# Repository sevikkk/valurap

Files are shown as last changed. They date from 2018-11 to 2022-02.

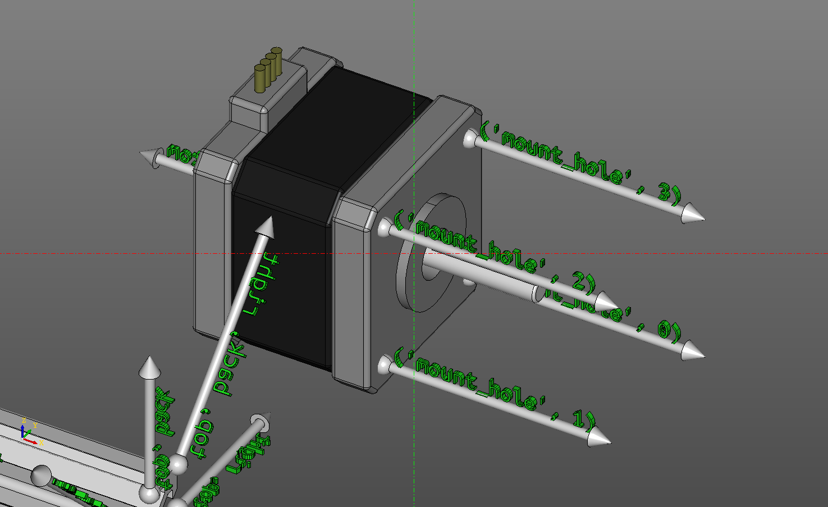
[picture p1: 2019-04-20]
zcad/examples/vitamins-3.png

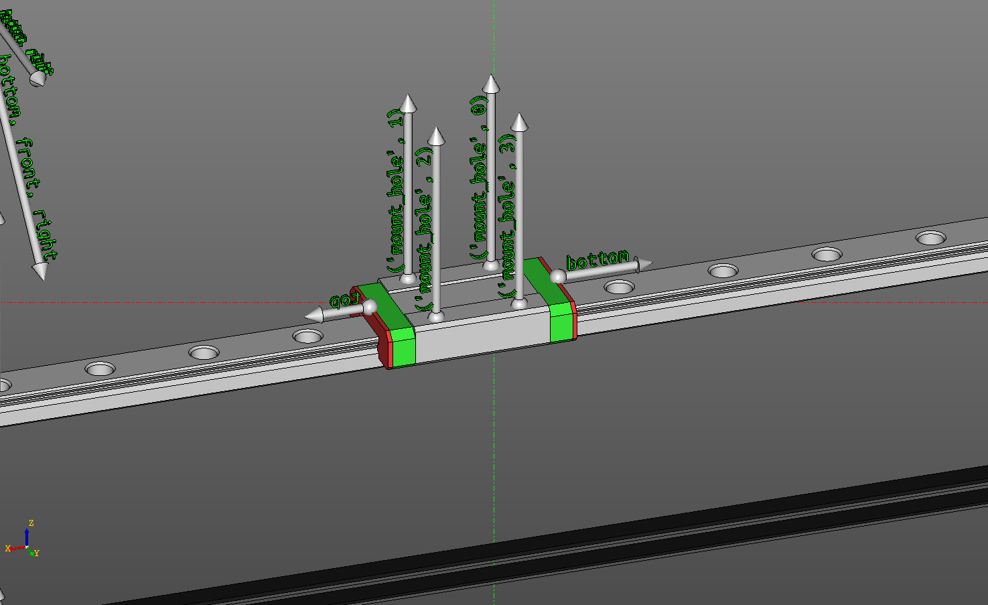
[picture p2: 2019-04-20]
zcad/examples/vitamins-4.png

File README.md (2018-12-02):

Next iteration of 3d printer
============================

Hardware
--------

* 20x20 and 20x40 v-profile, linear rails based on PVC rollers
* E3D Titan Aero Extruder

Electronics
-----------

* Orange PI Zero as main brains and network
* Mojo v3 as FPGA
* TMC2130 Stepper drivers

Directories
-----------

* fpga/ - verilog sources for SLX9 on Mojo 
* mojo_soft/ - software for mega32u4 on Mojo
* host_soft/ - python sources running on Zero
* pcbs/ - KiCad files for PCBs

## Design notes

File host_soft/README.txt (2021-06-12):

Orange PI Zero connections:

SPI1 - tms2103 SPI chain
TWI0 - SSD1306 OLED
UART1 - FPGA UART

Ext header:

     OPi        STM        OPi
PA02/UART2_RTS (RST)   |  PA10
PA03/UART2_CTS (BOOT0) |  PA18/TWI1_SCK
PA00/UART2_TX  (A10)   |  PA19/TWI1_SDA
PA01/UART2_RX  (A9)    |  PA07
GND                    |  PA06

EXT1:  EndStops
                             net
#NET "ext1_1" LOC = P58 | endstop_z1
#NET "ext1_2" LOC = P57 | endstop_z2
#NET "ext1_3" LOC = P67 | endstop_x1
#NET "ext1_4" LOC = P66 | endstop_y1
#NET "ext1_5" LOC = P75 | endstop_x2
#NET "ext1_6" LOC = P74 | endstop_y2
#NET "ext1_7" LOC = P79 | endstop_z3
#NET "ext1_8" LOC = P78 | endstop_z4

EXT2:
                         STM
NET "ext2_1" LOC = P81 | B9
NET "ext2_2" LOC = P80 | B8
NET "ext2_3" LOC = P83 | B7
NET "ext2_4" LOC = P82 | B6
NET "ext2_5" LOC = P85 | B5
NET "ext2_6" LOC = P84 | B4
NET "ext2_7" LOC = P88 | B3
NET "ext2_8" LOC = P87 | A15

EXT3:
                              net         STM
#NET "ext3_1" LOC = P93  |  stm_mosi  |  B15 (SPI2 MOSI)
#NET "ext3_2" LOC = P92  |  stm_rx    |  A3  (Serial2 RX)
#NET "ext3_3" LOC = P95  |  stm_miso  |  B14 (SPI2 MISO)
#NET "ext3_4" LOC = P94  |  stm_tx    |  A2  (Serial2 TX)
#NET "ext3_5" LOC = P98  |  stm_sck   |  B13 (SPI2 SCK)
#NET "ext3_6" LOC = P97  |  stm_int   |  A8
#NET "ext3_7" LOC = P100 |  stm_ss    |  B12 (SPI2 NSS)
#NET "ext3_8" LOC = P99  |  stm_alive |  C13 (LED1)

Disable wlan:
```
seva@orange:~$ cat /etc/modprobe.d/wlan.conf
blacklist xradio_wlan
```

Enable required devices:
```
seva@orange:~$ cat /boot/armbianEnv.txt
overlay_prefix=sun8i-h3
overlays=uart1 uart2 i2c1 i2c0 spi1 spi-spidev
param_spidev_spi_bus=1
usbstoragequirks=0x2537:0x1066:u,0x2537:0x1068:u
```

disable console on ttyS0:
```
sudo systemctl mask serial-getty@ttyS0.service
```

install cv2 into virtualenv
```
sudo apt-get install python3-opencv
cp /usr/lib/python3/dist-packages/cv2.cpython-37m-arm-linux-gnueabihf.so ~/.virtualenvs/valurap3/lib/python3.7/site-packages/
```

Enable NFS mount:
```
sudo apt-get update
sudo apt-get upgrade
sudo apt-get install nfs-common
```
add to automount entry fstab:
```
192.168.1.137:/Users/seva/src/sevasoft /home/seva/src/sevasoft nfs noauto,x-systemd.automount,soft,intr,x-systemd.idle-timeout=30 0 0
```

Virtualenv:

```
sudo apt-get install virtualenvwrapper python3-dev libffi-dev
mkvirtualenv --python=/usr/bin/python3.7 valurap3
pip install 'spidev==3.2' 'pyserial==3.4' 'pyserial-asyncio==0.4' ipython jupyter 'smbus2==0.2.3' 'luma.oled==3.1.0' OrangePi.GPIO
```

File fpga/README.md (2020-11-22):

Abbrevs
=======

* ASG - Acceleration step generator
* APG - Acceleration profile generator
* SP - SPeed integrator
* MSG - Motor step generator
* BE - buffer commands executor
* SE - S3G commands executor
* ES - EndStop debouncer

Outputs
=======

|Number | Name | Bits | Description
|--- | ---- | ---- | ---
|0  | ASG_DT_VAL | 31..0 | Length of each step in current cycle in clocks
|1  |  ASG_STEPS_VAL | 31..0 | Number of steps in current acceleration cycle
|2  | SP_CONFIG | | |
| 3 | MSG_ALL_PRE_N | 31..0 | Length of pre-pulse (after potential direction switch)
| 4 | MSG_ALL_PULSE_N | 31..0 | Length of pulse
| 5 | MSG_ALL_POST_N | 31..0 | Length of post-pulse
| 6  | MSG_X_VAL| 31..0 | Value to set X to
| 7 | MSG_CONFIG0 | 2..0 | ES mux select
|  | | 3 | Enable abort on ES change
|  | | 6..4 | SP mux select
|  | | 7 | Enable steps
|  | | 8 | Invert Direction
|  | | 9 | Set X value by stb[6]
|  | | 14..10 | Unused
|  | | 15 | Set enable output
| 8 | MSG_CONFIG1 | |
| 9 | MSG_CONFIG2 | |
| 10 | MSG_CONFIG3 | |
| 11 | MSG_CONFIG4 | |
| 12 | MSG_CONFIG5 | |
| 13 | ES_TIMEOUT | |
|14..62| Unused
|63 | SE_REG_LB | 31..0| Looped back to Input 63
 
Inputs
======

| Number | Name | Bits | Description
| --- | ---- | ---- | ---
|  0 | BE_STATUS
|  1 | APG_STATUS
|  2 | ES_STATUS
|  3 | FIFO_FREE_SPACE
|  4 | FIFO_DATA_COUNT
|  5 | MOTOR1_HOLD_X
|  6 | MOTOR2_HOLD_X
|  7 | MOTOR3_HOLD_X
|  8 | MOTOR4_HOLD_X
|  9 | MOTOR5_HOLD_X
|  10 | MOTOR6_HOLD_X
|  11 | MOTOR7_HOLD_X
|  12 | MOTOR8_HOLD_X
|  13 | MOTOR9_HOLD_X
|  14 | MOTOR10_HOLD_X
|  15 | MOTOR11_HOLD_X
|  16 | MOTOR12_HOLD_X
|  17 | MOTOR1_HOLD_X
|  18 | MOTOR2_HOLD_X
|  19 | MOTOR3_HOLD_X
|  20 | MOTOR4_HOLD_X
|  21 | MOTOR5_HOLD_X
|  22 | MOTOR6_HOLD_X
|  23 | MOTOR7_HOLD_X
|  24 | MOTOR8_HOLD_X
|  25 | MOTOR9_HOLD_X
|  26 | MOTOR10_HOLD_X
|  27 | MOTOR11_HOLD_X
|  28 | MOTOR12_HOLD_X
|  29..61 | Unused
| 62 | PENDING_INTS | 31..0 | Pending interrupts
| 63 | SE_REG_LB | 31..0 | Loopback from output 63

Interrupts
==========

|Number | Name | Description
|--- | ---- | ---
| 0 | BE_DONE | Buf Executor done (due to BUF_DONE)
| 1 | ASG_LOAD | Current accel cycle is almost done, load of next cycle params required
| 2 | ASG_DONE | Last cycle is done
| 3 | ASG_ABORT | ASG requested abort due to buffer underflow/etc
| 2..7| Unused
| 8..15 | APG_ABORTS_DONE | Aborts for corresponding channel are done
| 16..30| Unused
| 31 | SE_INT_LB | Looped back to Strobe 31

Strobes
=======

|Number | Name | Description
|--- | ---- | ---
| 0| BE start
| 1| BE abort
| 2| ASG start
| 3| ASG abort
| 4| ASG load done
| 5| SP zero | set x=0 for all SPs
| 6| MSG set X | set x=MSG_X_VAL for selected by MSG_CONFIG channels
| 7| ES unlock
| 8..15| Abort APG channel 0..7
| 16..30| Unused
| 31 | SE_INT_LB | Looped back to Int 31

S3G proto
============

Request
-------

| Offset | Size | Description
|---|---|---
| 0 | 1 |  0xD5 - header
| 1 | 1 |  Payload length (N)
| 2 | 2 |  Tag - will be copied to reply
| 4 | 1 |  Command Code
| 5 | N - 3 |  Arguments
|  N + 1| 1 | CRC

Reply
-----

| Offset | Size | Description
|---|---|---
| 0 | 1 |  0xD5 - header
| 1 | 1 |  Payload length (N)
| 2 | 2 |  Tag - copied from request or 0xFFFF
| 4 | 1 |  Reply Code
| 5 | N - 3 |  Arguments
|  N + 1| 1 | CRC

Reply Codes
-----------
|Code | Name | Description
|-----|---|---
|  80 | Interrupt | Interrupt report (originated by device)
| 0x80  | Error | Error
| 0x81  | OK | Success, can be followed by reply args
| 0x82  | BufError | Error writing to buf_exec memory because of new command arrival
| 0x85  | Unknown | Unknown command

Command Codes
-------------

|Command | CMD | Name | Args | Reply
|---|-----|---|---|---
|  0 | VERSION  | Version | -- |  OK 0xBA 0xCE
|  27 | EXT_VER  | Extended Version | -- | OK 0x01 0x00 0x01 0x00 0xCE 0x00 0x00 0x00
|  60 | OUTPUT  | Write output | 0: reg num 1..4: value | OK
|  61 | INPUT  | Read input | 0: input num | OK 0..3: Value
|  62 | STB | Send Strobes | 0..3: Mask | OK
|  63 | CLEAR  | Clear pending interrupts| 0..3: Mask
|  64 | MASK  | Mask interrupts| 0..3: Mask
|  65 | Unused (was WRITE_BUFFER in old version)
|  66 | WRITE_FIFO | Put data into buf_exec Fifo | 0: Word count 1..1+N*5: Data| {OK, BufError} 0..3: Fifo free space

Buf Executor Commands
=====================

|Format | Name | Description
|---|---|---
|0 0 X:6 X:32 | Unused
|0 1 reg_num:6 value:32 | OUTPUT | Write value to output
|1 0 0:6 X:32 | NOP | Nop
|1 0 1:6 mask:32 | STB | Send STBs
|1 0 2:6 mask:32 | WAIT_ALL | Wait for all Ints
|1 0 3:6 mask:32 | WAIT_ANY | Wait for any of Ints
|1 0 4:6 mask:32 | CLEAR | Clear INTs
|1 0 5:6 int_ext:1 value:31 | WAIT_FIFO | Wait while local or external fifo has enough data inside
|1 0 6:6 X:24 addr:8 | PARAM_ADDR | Set address pointer for APG param store
|1 0 7:6 value:32 | PARAM_WRITE_HI | Write to high 32 bits of current address
|1 0 8:6 value:32 | PARAM_WRITE_LO | Write to low 32 bits of current address, and keep it as is
|1 0 9-14:6 value:32 | PARAM_WRITE_LO_{N} | Increment current address for {N} and write to low 32 bits
|1 0 15:6 value:32 | PARAM_WRITE_LO_NC | Increment current address to 0 of next channel(32 values block) and write to low 32 bits
|1 0 5-62:6 X:32 | Unused
|1 0 63:6 X:32 | DONE | Halt and report
|1 1 X:6 X:32 | Unused

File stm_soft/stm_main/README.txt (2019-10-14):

Skeleton is generated by STM32CubeMX v5.3.0.

toolchain is from STM32 Cores by STMicroelectronics v1.7.0 installed into Arduino IDE v1.8.10.

Drivers and Middlewares folders are omitted from git repo.

env.sh file sets environment variables needed for build.

Looks like for Makefile based project "Regenerate code" parses preexisting Makefile in the wrong way.
So before regenerating delete current makefile, press "generate code" and add back lines with custom
sources at the end of file.

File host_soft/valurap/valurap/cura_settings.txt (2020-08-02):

=========== Custom FFF printer ===========
   general
     id Custom FFF printer
     name Custom FFF printer
     version 4
   metadata
     group_id 9e8ac431-269c-41fb-836f-cbf8574d42b9
     setting_version 11
     type machine
   containers:
     0 Custom FFF printer_user ('user', 'Custom FFF printer_user.inst.cfg')
        adhesion_type: 'skirt'
        draft_shield_enabled: 'True'
        ooze_shield_enabled: 'True'
        prime_tower_brim_enable: 'False'
        prime_tower_enable: 'True'
        prime_tower_position_x: '120'
        prime_tower_position_y: '100'
        retraction_combing: 'all'
        support_enable: 'True'
     6 Custom FFF printer_settings ('definition_changes', 'Custom FFF printer_settings.inst.cfg')
        machine_center_is_zero: 'True'
        machine_depth: '300'
        machine_extruder_count: '1'
        machine_heated_bed: 'True'
        machine_height: '400'
        machine_start_gcode:
          | G28 ;Home
          | G92 E0
          | G1 F200 E3
          | G92 E0
        machine_width: '320'
  extruders:
    0: --------- Extruder 1 ('extruders', 'custom_extruder_1 #2.extruder.cfg') ------- 
        general
          id: custom_extruder_1 #2
          name: Extruder 1
          version: 4
        metadata
          enabled: True
          machine: Custom FFF printer
          position: 0
          setting_version: 11
          type: extruder_train
        containers:
          0 custom_extruder_1 #2_user ('user', 'custom_extruder_1 #2_user.inst.cfg')
             clean_between_layers: 'True'
             infill_pattern: 'zigzag'
             infill_randomize_start_location: 'True'
             infill_sparse_density: '7'
             infill_wall_line_count: '1'
             prime_tower_min_volume: '1'
             prime_tower_wipe_enabled: 'False'
             retract_at_layer_change: 'True'
             retraction_amount: '1'
             retraction_speed: '10'
             speed_print: '100'
             speed_travel: '150'
             support_use_towers: 'False'
             switch_extruder_retraction_amount: '5'
             travel_avoid_supports: 'True'
             wipe_brush_pos_x: '-170'
             wipe_move_distance: '15'
             wipe_repeat_count: '3'
             wipe_retraction_enable: 'False'
             z_seam_type: 'random'
          6 custom_extruder_1 #2_settings ('definition_changes', 'custom_extruder_1 #2_settings.inst.cfg')
             material_diameter: '1.75'
=========== Custom FFF printer #2 ===========
   general
     id Custom FFF printer #2
     name Custom FFF printer #2
     version 4
   metadata
     group_id 3304d7be-4387-4436-b254-41188bad6fcd
     setting_version 11
     type machine
   containers:
     0 Custom FFF printer #2_user ('user', 'Custom FFF printer #2_user.inst.cfg')
        -- empty --
     6 Custom FFF printer #2_settings ('definition_changes', 'Custom FFF printer #2_settings.inst.cfg')
        -- empty --
  extruders:
    0: --------- Extruder 1 ('extruders', 'custom_extruder_1 #3.extruder.cfg') ------- 
        general
          id: custom_extruder_1 #3
          name: Extruder 1
          version: 4
        metadata
          enabled: True
          machine: Custom FFF printer #2
          position: 0
          setting_version: 11
          type: extruder_train
        containers:
          0 custom_extruder_1 #3_user ('user', 'custom_extruder_1 #3_user.inst.cfg')
             -- empty --
          6 custom_extruder_1 #3_settings ('definition_changes', 'custom_extruder_1 #3_settings.inst.cfg')
             -- empty --

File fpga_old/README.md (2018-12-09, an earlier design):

Abbrevs
=======

* ASG - Acceleration step generator
* APG - Acceleration profile generator
* MSG - Motor step generator
* BE - buffer commands executor
* SE - S3G commands executor

Outputs
=======

|Number | Name | Bits | Description
|--- | ---- | ---- | ---
|0  |  LEDS | 7..0 | On-board LEDs
|  | | 31..8 | Unused
|1  |  ASG_STEPS_VAL | 31..0 | Number of steps in current acceleration cycle
|2  | ASG_DT_VAL | 31..0 | Length of each step in current cycle in clocks
|3  | ASG_CONTROL | 0 | Set steps limit
| | | 1 | Set DT limit
| | | 2 | Reset steps
| | | 3 | Reset DT
| | | 4..7 | Unused
| | | 8 | APG_X set X
| | | 9 | APG_X set V
| | | 10 | APG_X set A
| | | 11 | APG_X set J
| | | 12 | APG_X set JJ
| | | 13 | APG_X set target V
| 4 | MSG_ALL_PRE_N | 31..0 | Length of pre-pulse (after potential direction switch)
| 5 | MSG_ALL_PULSE_N | 31..0 | Length of pulse
| 6 | MSG_ALL_POST_N | 31..0 | Length of post-pulse
| 7 | MSG_CONTROL | 0 | X-motor enable (inverted output, 0 - disabled, 1 - enabled)
| | | 31..1 | Unused
| 8 | APG_X_X_VAL_LO | 31..0 | X channel X value (lower half)
| 9 | APG_X_X_VAL_HI | 31..0 | X channel X value (higher half)
| 10 | APG_X_V_VAL | 31..0 | X channel V value
| 11 | APG_X_A_VAL | 31..0 | X channel A value
| 12 | APG_X_J_VAL | 31..0 | X channel J value
| 13 | APG_X_JJ_VAL | 31..0 | X channel JJ value
| 14 | APG_X_TARGET_V_VAL | 31..0 | X channel target velocity value
| 15 | APG_X_ABORT_A_VAL | 31..0 | X channel abort acceleration value
|16..61| Unused
|62 | BE_START_ADDR | 15..0 | Start address for buf_exec
|63 | SE_REG_LB | 31..0| Looped back to Input 63
 
Inputs
======

| Number | Name | Bits | Description
| --- | ---- | ---- | ---
|  0 | ASG_DT | 31..0 | Current accel step clock number
|  1 | ASG_STEP | 31..0 | Current step in accel cycle
|  2..61 | Unused
|  62 | BE_CONTROL | 31 | BE_BUSY - buf_exec is executing
| | | 30 | BE_WAITING - buf_exec is waiting for interrupt
| | |29..24| Unused
| | | 23..16 | BE_ERROR - current error code
| | | 15..0 | BE_PC - current PC of buf_exec
| 63 | SE_REG_LB | 31..0 | Loopback from output 63

Interrupts
==========

|Number | Name | Description
|--- | ---- | ---
| 0 | ASG_DONE | Current accel cycle is done, load required
| 1 | ASG_ABORT | Aborting current activity as new params were not loaded in time
| 2..29| Unused
| 30 | BE_COMPLETE | buf_exec done executing
| 31 | SE_INT_LB | Looped back to Strobe 0

Strobes
=======

|Number | Name | Description
|--- | ---- | ---
| 0 | ASG_LOAD | Load parameters of current accel cycle
| 1..28| Unused
| 29 | BE_START | Start execution for buf_exec
| 30 | BE_ABORT | Abort buf_exec execution
| 31 | SE_INT_LB | Looped back to Int 31

S3G proto
============

Request
-------

| Offset | Size | Description
|---|---|---
| 0 | 1 |  0xD5 - header
| 1 | 1 |  Payload length (N)
| 2 | 2 |  Tag - will be copied to reply
| 4 | 1 |  Command Code
| 5 | N - 3 |  Arguments
|  N + 1| 1 | CRC

Reply
-----

| Offset | Size | Description
|---|---|---
| 0 | 1 |  0xD5 - header
| 1 | 1 |  Payload length (N)
| 2 | 2 |  Tag - copied from request or 0xFFFF
| 4 | 1 |  Reply Code
| 5 | N - 3 |  Arguments
|  N + 1| 1 | CRC

Reply Codes
-----------
|Code | Name | Description
|-----|---|---
|  80 | Interrupt | Interrupt report (originated by device)
| 0x80  | Error | Error
| 0x81  | OK | Success, can be followed by reply args
| 0x82  | BufError | Error writing to buf_exec memory because of new command arrival
| 0x85  | Unknown | Unknown command

Command Codes
-------------

|Command | CMD | Name | Args | Reply
|---|-----|---|---|---
|  0 | VERSION  | Version | -- |  OK 0xBA 0xCE
|  27 | EXT_VER  | Extended Version | -- | OK 0x01 0x00 0x01 0x00 0xCE 0x00 0x00 0x00
|  60 | OUTPUT  | Write output | 0: reg num 1..4: value | OK
|  61 | INPUT  | Read input | 0: input num | OK 0..3: Value
|  62 | STB | Send Strobes | 0..3: Mask | OK
|  63 | CLEAR  | Clear pending interrupts| 0..3: Mask
|  64 | MASK  | Mask interrupts| 0..3: Mask
|  65 | WRITE_BUFFER | Write buf_exec memory| 0: Word count 1..2: Offset 3..3+N*5: Data| {OK, BufError} 0..1: Addr 2: Curent Error 3..4: PC

Buf Executor Commands
=====================

|Format | Name | Description
|---|---|---
|0 0 X:6 X:32 | Unused
|0 1 reg_num:6 value:32 | OUTPUT | Write value to output
|1 0 0:6 X:32 | NOP | Nop
|1 0 1:6 mask:32 | STB | Send STBs
|1 0 2:6 mask:32 | WAIT_ALL | Wait for all Ints
|1 0 3:6 mask:32 | WAIT_ANY | Wait for any of Ints
|1 0 4:6 masK:32 | CLEAR | Clear INTs
|1 0 5-62:6 X:32 | Unused
|1 0 63:6 X:32 | DONE | Halt and report
|1 1 X:6 X:32 | Unused

Utilization for single full channel
===================================

```
Device Utilization Summary:

Slice Logic Utilization:
  Number of Slice Registers:                 1,395 out of  11,440   12%
    Number used as Flip Flops:               1,395
    Number used as Latches:                      0
    Number used as Latch-thrus:                  0
    Number used as AND/OR logics:                0
  Number of Slice LUTs:                      2,315 out of   5,720   40%
    Number used as logic:                    2,303 out of   5,720   40%
      Number using O6 output only:           1,690
      Number using O5 output only:             122
      Number using O5 and O6:                  491
      Number used as ROM:                        0
    Number used as Memory:                       2 out of   1,440    1%
      Number used as Dual Port RAM:              0
      Number used as Single Port RAM:            0
      Number used as Shift Register:             2
        Number using O6 output only:             2
        Number using O5 output only:             0
        Number using O5 and O6:                  0
    Number used exclusively as route-thrus:     10
      Number with same-slice register load:      5
      Number with same-slice carry load:         5
      Number with other load:                    0

Slice Logic Distribution:
  Number of occupied Slices:                   712 out of   1,430   49%
  Nummber of MUXCYs used:                      764 out of   2,860   26%
  Number of LUT Flip Flop pairs used:        2,524
    Number with an unused Flip Flop:         1,180 out of   2,524   46%
    Number with an unused LUT:                 209 out of   2,524    8%
    Number of fully used LUT-FF pairs:       1,135 out of   2,524   44%
    Number of slice register sites lost
      to control set restrictions:               0 out of  11,440    0%

  A LUT Flip Flop pair for this architecture represents one LUT paired with
  one Flip Flop within a slice.  A control set is a unique combination of
  clock, reset, set, and enable signals for a registered element.
  The Slice Logic Distribution report is not meaningful if the design is
  over-mapped for a non-slice resource or if Placement fails.

IO Utilization:
  Number of bonded IOBs:                        23 out of     102   22%
    Number of LOCed IOBs:                       20 out of      23   86%
    IOB Flip Flops:                              1

Specific Feature Utilization:
  Number of RAMB16BWERs:                        21 out of      32   65%
  Number of RAMB8BWERs:                          0 out of      64    0%
  Number of BUFIO2/BUFIO2_2CLKs:                 0 out of      32    0%
  Number of BUFIO2FB/BUFIO2FB_2CLKs:             0 out of      32    0%
  Number of BUFG/BUFGMUXs:                       1 out of      16    6%
    Number used as BUFGs:                        1
    Number used as BUFGMUX:                      0
  Number of DCM/DCM_CLKGENs:                     0 out of       4    0%
  Number of ILOGIC2/ISERDES2s:                   0 out of     200    0%
  Number of IODELAY2/IODRP2/IODRP2_MCBs:         0 out of     200    0%
  Number of OLOGIC2/OSERDES2s:                   1 out of     200    1%
    Number used as OLOGIC2s:                     1
    Number used as OSERDES2s:                    0
  Number of BSCANs:                              0 out of       4    0%
  Number of BUFHs:                               0 out of     128    0%
  Number of BUFPLLs:                             0 out of       8    0%
  Number of BUFPLL_MCBs:                         0 out of       4    0%
  Number of DSP48A1s:                            0 out of      16    0%
  Number of ICAPs:                               0 out of       1    0%
  Number of MCBs:                                0 out of       2    0%
  Number of PCILOGICSEs:                         0 out of       2    0%
  Number of PLL_ADVs:                            0 out of       2    0%
  Number of PMVs:                                0 out of       1    0%
  Number of STARTUPs:                            0 out of       1    0%
  Number of SUSPEND_SYNCs:                       0 out of       1    0%
```

Utilization for two full channels
===================================

```
Device Utilization Summary:

Slice Logic Utilization:
  Number of Slice Registers:                 1,856 out of  11,440   16%
    Number used as Flip Flops:               1,856
    Number used as Latches:                      0
    Number used as Latch-thrus:                  0
    Number used as AND/OR logics:                0
  Number of Slice LUTs:                      3,304 out of   5,720   57%
    Number used as logic:                    3,291 out of   5,720   57%
      Number using O6 output only:           2,336
      Number using O5 output only:             152
      Number using O5 and O6:                  803
      Number used as ROM:                        0
    Number used as Memory:                       2 out of   1,440    1%
      Number used as Dual Port RAM:              0
      Number used as Single Port RAM:            0
      Number used as Shift Register:             2
        Number using O6 output only:             2
        Number using O5 output only:             0
        Number using O5 and O6:                  0
    Number used exclusively as route-thrus:     11
      Number with same-slice register load:      5
      Number with same-slice carry load:         6
      Number with other load:                    0

Slice Logic Distribution:
  Number of occupied Slices:                 1,010 out of   1,430   70%
  Nummber of MUXCYs used:                    1,272 out of   2,860   44%
  Number of LUT Flip Flop pairs used:        3,508
    Number with an unused Flip Flop:         1,779 out of   3,508   50%
    Number with an unused LUT:                 204 out of   3,508    5%
    Number of fully used LUT-FF pairs:       1,525 out of   3,508   43%
    Number of slice register sites lost
      to control set restrictions:               0 out of  11,440    0%

  A LUT Flip Flop pair for this architecture represents one LUT paired with
  one Flip Flop within a slice.  A control set is a unique combination of
  clock, reset, set, and enable signals for a registered element.
  The Slice Logic Distribution report is not meaningful if the design is
  over-mapped for a non-slice resource or if Placement fails.

IO Utilization:
  Number of bonded IOBs:                        26 out of     102   25%
    Number of LOCed IOBs:                       20 out of      26   76%
    IOB Flip Flops:                              2

Specific Feature Utilization:
  Number of RAMB16BWERs:                        21 out of      32   65%
  Number of RAMB8BWERs:                          0 out of      64    0%
  Number of BUFIO2/BUFIO2_2CLKs:                 0 out of      32    0%
  Number of BUFIO2FB/BUFIO2FB_2CLKs:             0 out of      32    0%
  Number of BUFG/BUFGMUXs:                       1 out of      16    6%
    Number used as BUFGs:                        1
    Number used as BUFGMUX:                      0
  Number of DCM/DCM_CLKGENs:                     0 out of       4    0%
  Number of ILOGIC2/ISERDES2s:                   0 out of     200    0%
  Number of IODELAY2/IODRP2/IODRP2_MCBs:         0 out of     200    0%
  Number of OLOGIC2/OSERDES2s:                   2 out of     200    1%
    Number used as OLOGIC2s:                     2
    Number used as OSERDES2s:                    0
  Number of BSCANs:                              0 out of       4    0%
  Number of BUFHs:                               0 out of     128    0%
  Number of BUFPLLs:                             0 out of       8    0%
  Number of BUFPLL_MCBs:                         0 out of       4    0%
  Number of DSP48A1s:                            0 out of      16    0%
  Number of ICAPs:                               0 out of       1    0%
  Number of MCBs:                                0 out of       2    0%
  Number of PCILOGICSEs:                         0 out of       2    0%
  Number of PLL_ADVs:                            0 out of       2    0%
  Number of PMVs:                                0 out of       1    0%
  Number of STARTUPs:                            0 out of       1    0%
  Number of SUSPEND_SYNCs:                       0 out of       1    0%
```

Utilization for 2 full channels and 2 XVA only channels
=======================================================

Also X is limited to 48 bits. But it does not fit anyway.
Patch is in `patch/4chan.patch`.

```
Slice Logic Utilization:
 Number of Slice Registers:            2523  out of  11440    22%
 Number of Slice LUTs:                 7017  out of   5720   122% (*)
    Number used as Logic:              7015  out of   5720   122% (*)
    Number used as Memory:                2  out of   1440     0%
       Number used as SRL:                2

Slice Logic Distribution:
 Number of LUT Flip Flop pairs used:   7212
   Number with an unused Flip Flop:    4689  out of   7212    65%
   Number with an unused LUT:           195  out of   7212     2%
   Number of fully used LUT-FF pairs:  2328  out of   7212    32%
   Number of unique control sets:        73

IO Utilization:
 Number of IOs:                          37
 Number of bonded IOBs:                  32  out of    102    31%

Specific Feature Utilization:
 Number of Block RAM/FIFO:               21  out of     32    65%
    Number using Block RAM only:         21
 Number of BUFG/BUFGCTRLs:                1  out of     16     6%
```

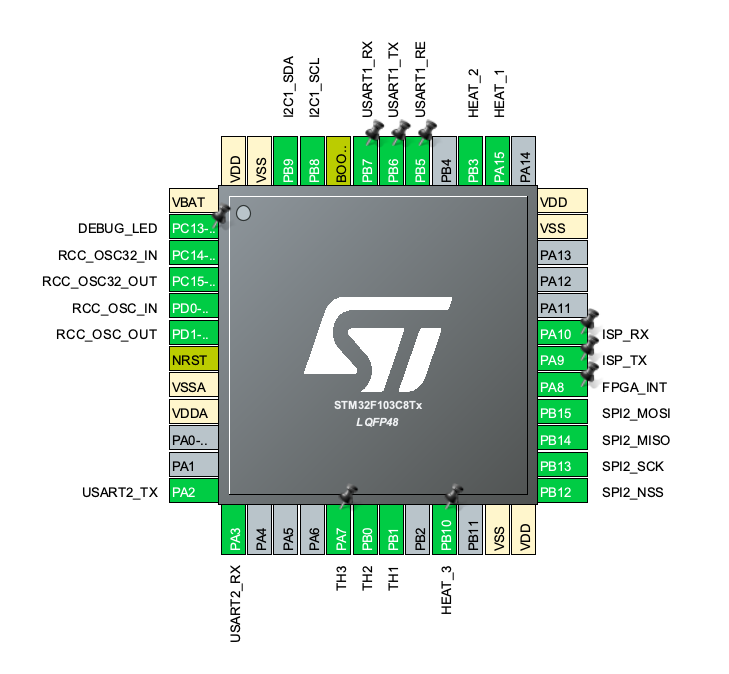
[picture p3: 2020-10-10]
stm_soft/stm_main/stm_main_pins.png

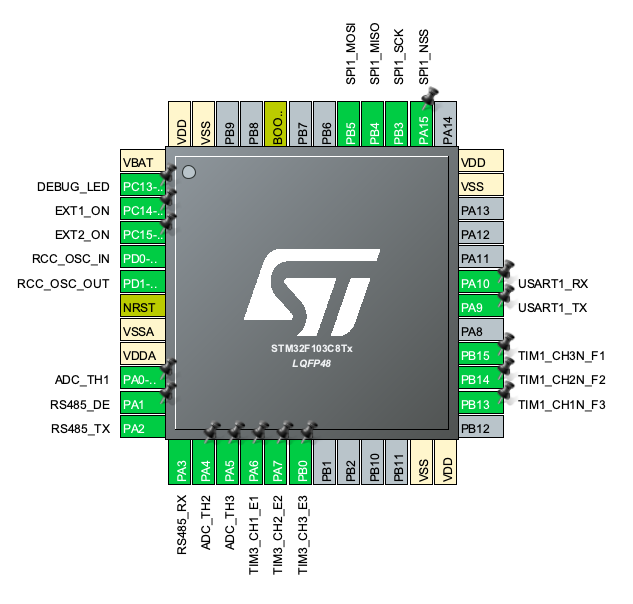
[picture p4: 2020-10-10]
stm_soft/stm_thermo/stm_thermo_pins.png

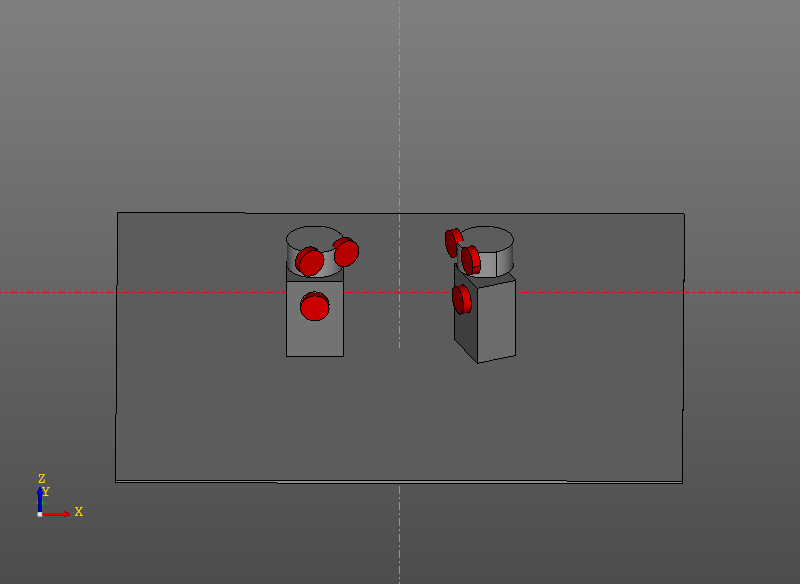
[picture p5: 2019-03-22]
zcad/examples/robot.png

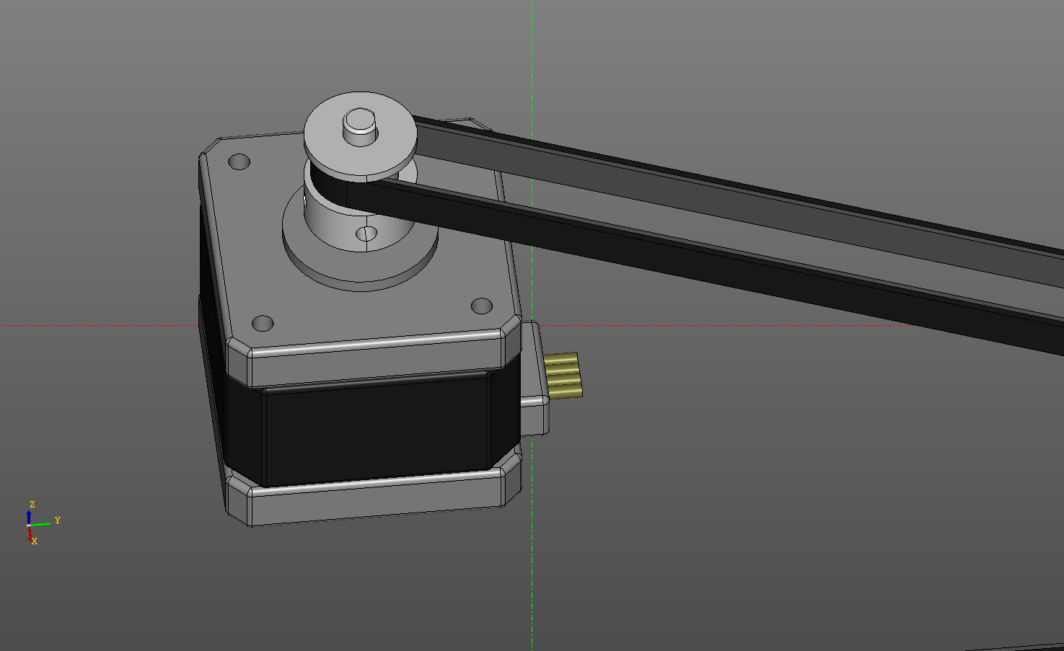
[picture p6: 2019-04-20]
zcad/examples/vitamins-2.png

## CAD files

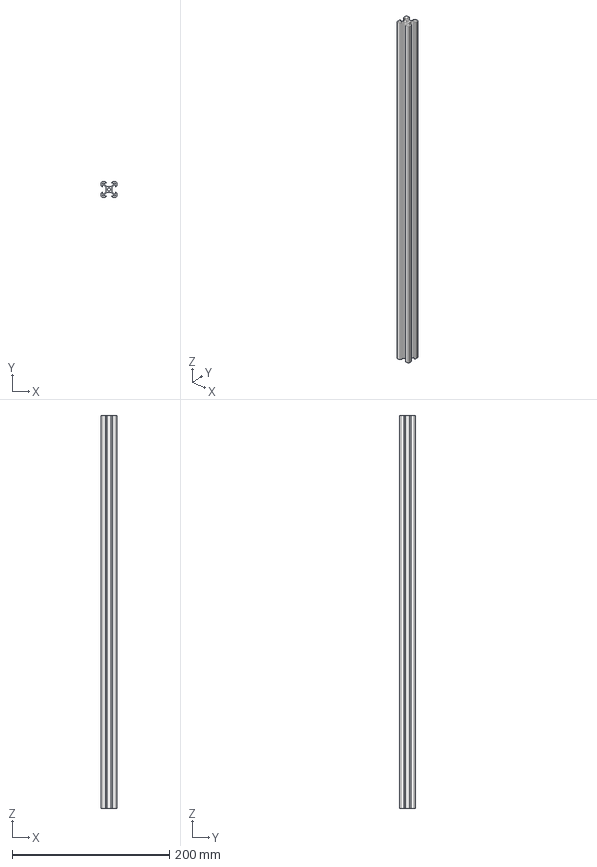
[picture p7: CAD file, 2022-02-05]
freecad/extra_fcstds/frame_assembly.FCStd
20.0 x 20.0 x 500.0 mm

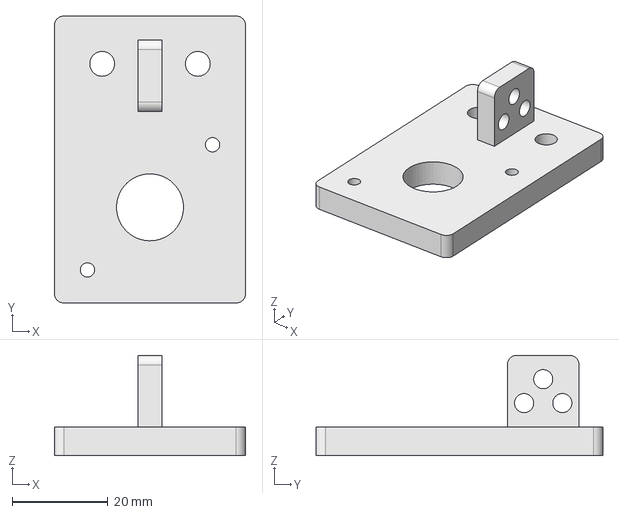
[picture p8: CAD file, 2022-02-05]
freecad/extra_fcstds/camera_mount.FCStd
40.0 x 60.0 x 21.0 mm

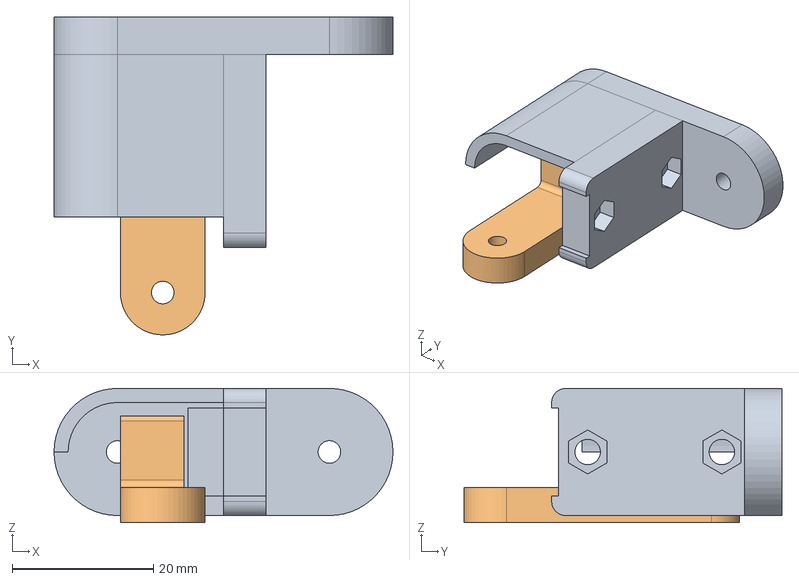
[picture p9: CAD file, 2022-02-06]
freecad/left_z_opto_mount.FCStd
48.0 x 45.0 x 19.0 mm
opto_mount
opto_probe

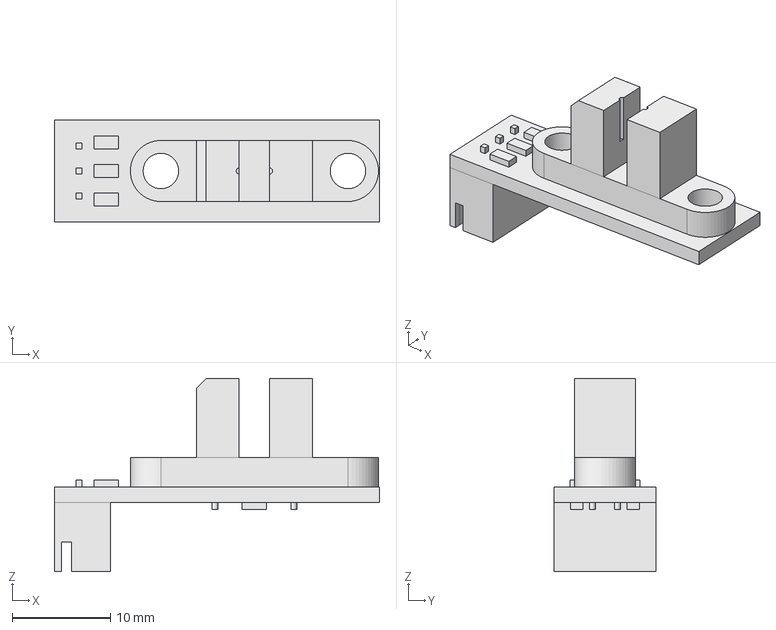
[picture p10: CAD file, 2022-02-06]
freecad/vitamins/optostop.FCStd
33.0 x 10.4 x 19.6 mm

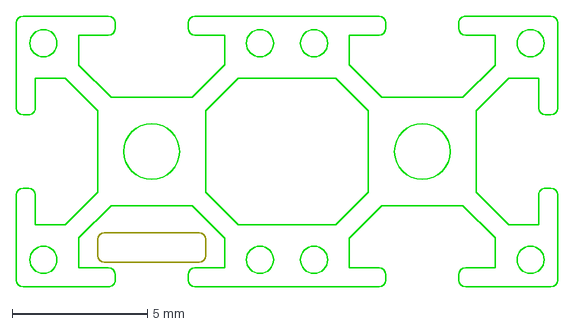
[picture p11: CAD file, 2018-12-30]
scad/vitamins/paratslot.dxf
20.0 x 10.0 mm

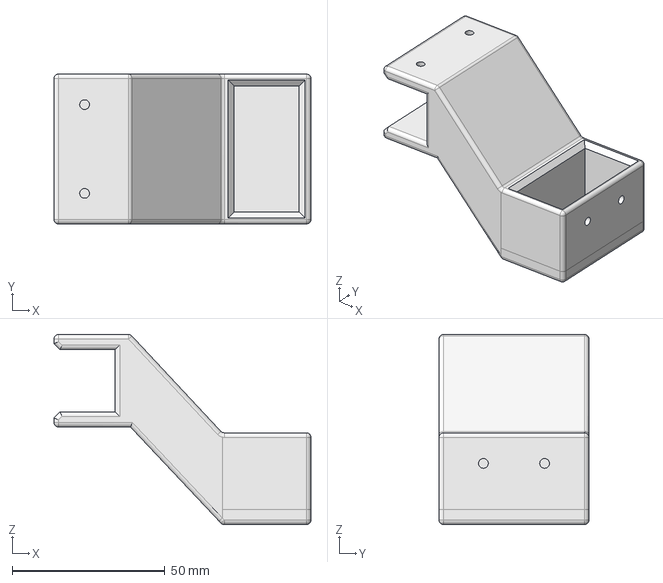
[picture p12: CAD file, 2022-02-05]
freecad/extra_fcstds/second_heater_holder.FCStd
84.0 x 49.0 x 62.2 mm

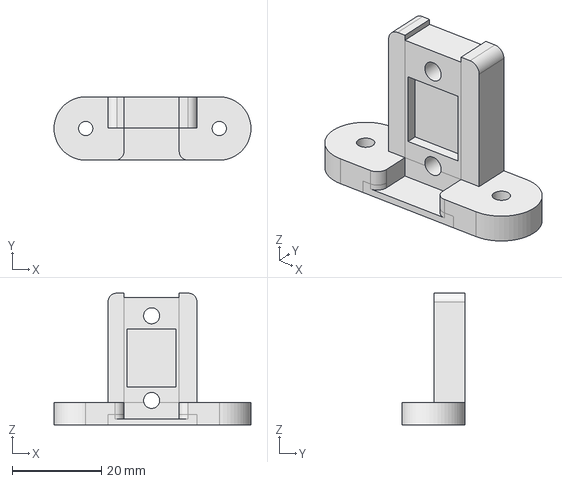
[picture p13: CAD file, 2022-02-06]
freecad/left_x_opto_mount.FCStd
44.2 x 14.2 x 29.6 mm

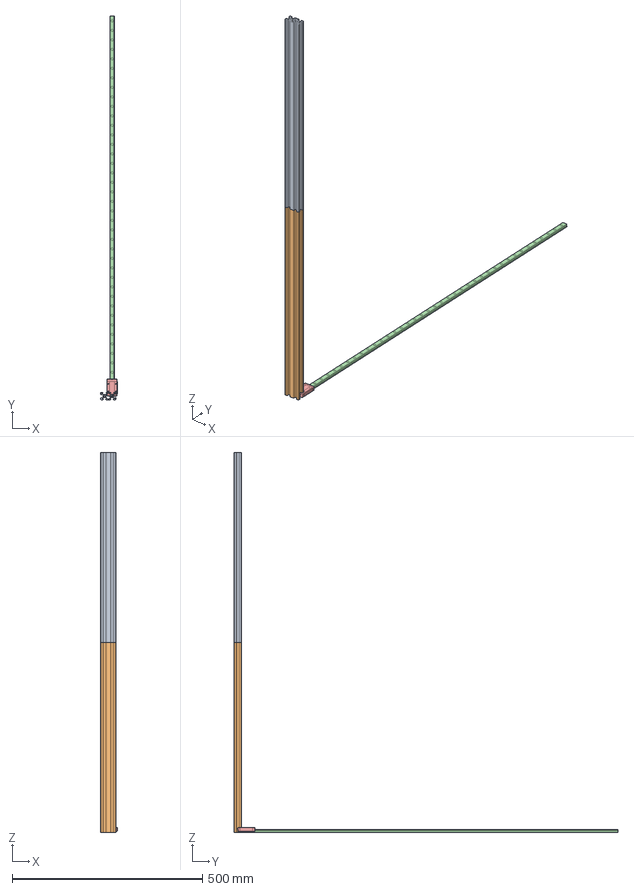
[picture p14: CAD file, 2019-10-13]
freecad/vitamins/mgr12r450.FCStd
43.5 x 1010.0 x 1000.0 mm
Clear anodized V-Slot 20x40mm Length: 1000.0
Clear anodized V-Slot 20x40mm Length: 500.0
MGNR12R450
MGNR12R1000
MGN12H
MGN12H_001
MGNR12R1000_001
MGNR12R450_001

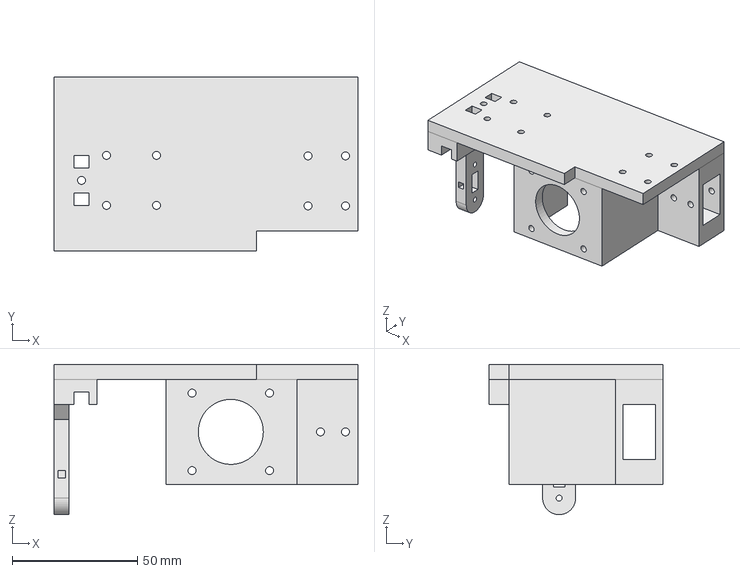
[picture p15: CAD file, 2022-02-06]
freecad/left_y_carriage_plate.FCStd
121.6 x 69.5 x 60.1 mm

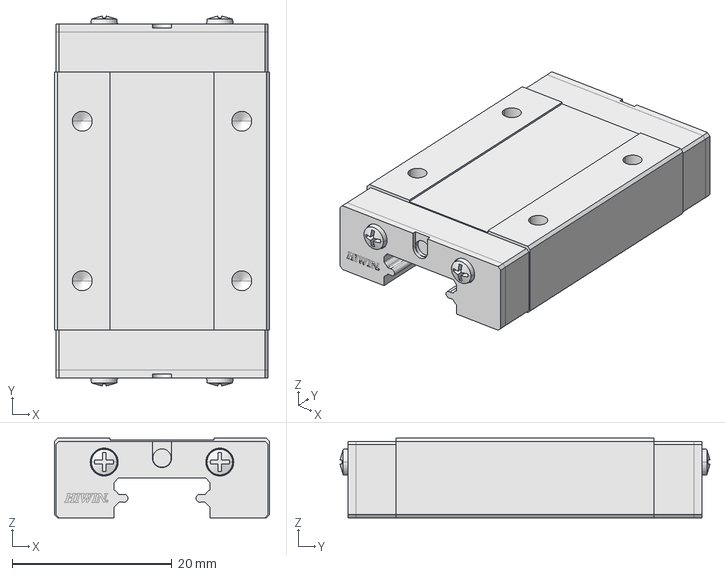
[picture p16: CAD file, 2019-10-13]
freecad/vitamins/mgn12h.FCStd
27.0 x 46.4 x 10.0 mm

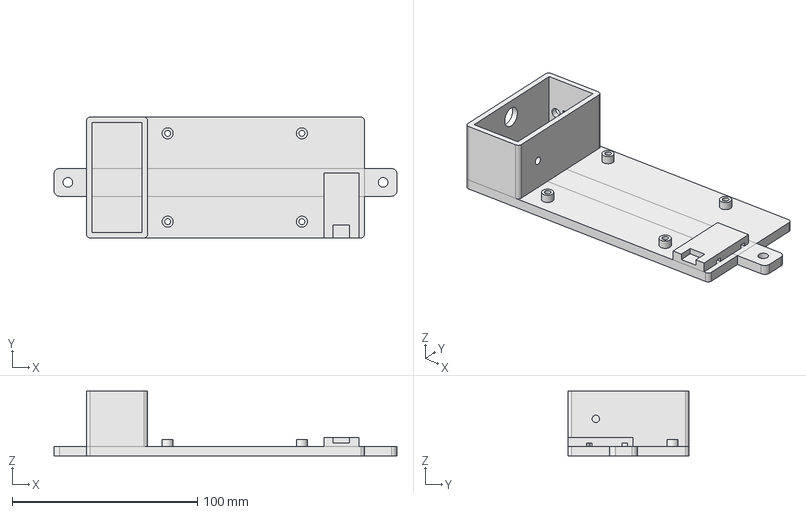
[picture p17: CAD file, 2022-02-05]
freecad/extra_fcstds/tc_box.FCStd
185.0 x 65.2 x 35.0 mm

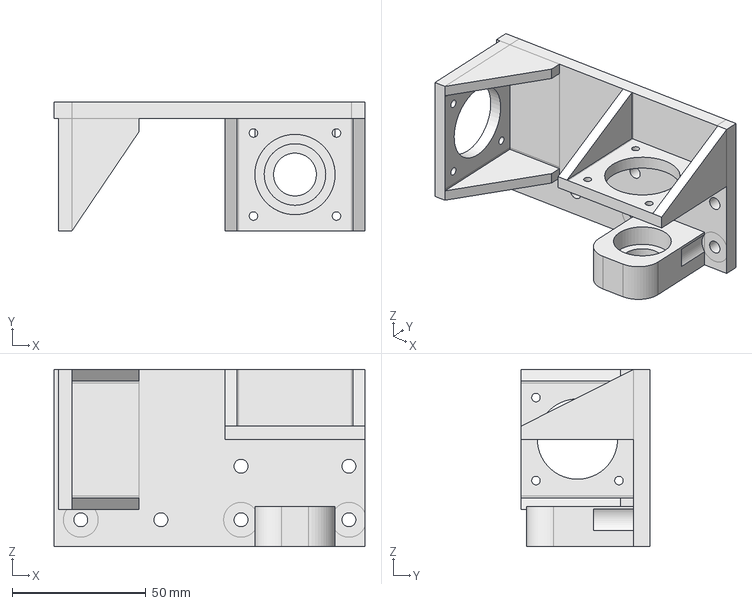
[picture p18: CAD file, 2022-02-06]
freecad/left_y_motor_plate.FCStd
116.2 x 48.0 x 66.2 mm

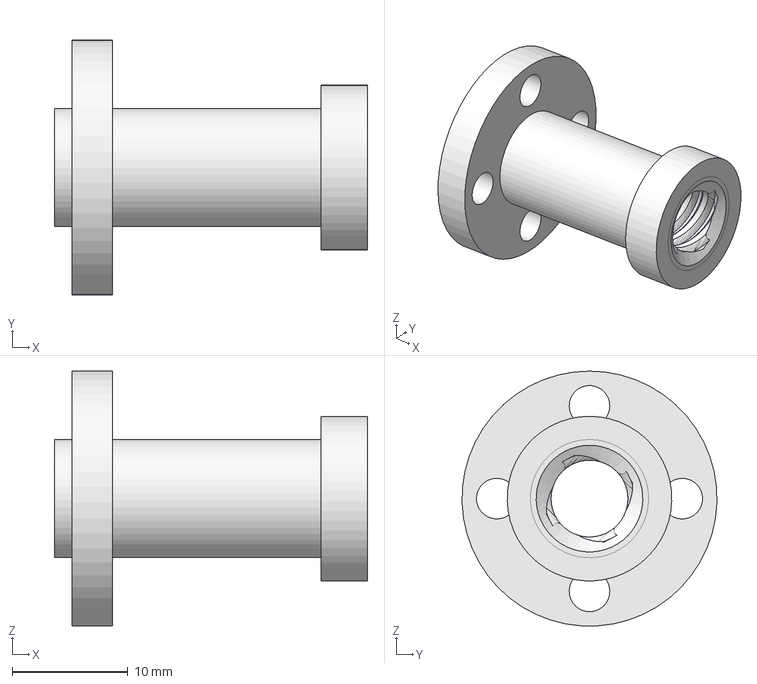
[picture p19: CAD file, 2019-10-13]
freecad/vitamins/nut8.FCStd
27.0 x 22.0 x 22.0 mm

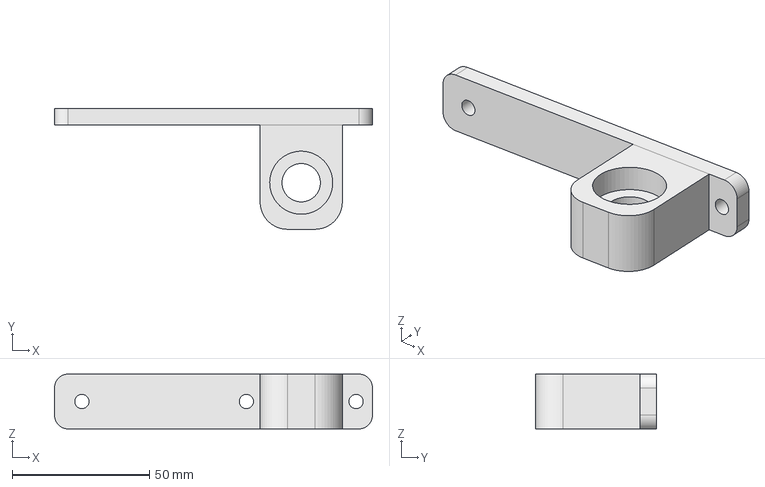
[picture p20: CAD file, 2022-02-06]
freecad/left_z_rod_support.FCStd
116.0 x 44.0 x 20.0 mm

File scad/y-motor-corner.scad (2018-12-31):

module y_motor_corner(is_left) {
    k = is_left?1:0;
    mirror([k,0,0])
    difference() {
        union() {
            difference() {
                union() {
                    translate([-25,-25,0]) cube([50,50,5]);
                    translate([22,-25,-45]) cube([3,50,50]);
                    translate([-25,-25,-45]) cube([50,3,50]);
                    translate([-25,22,-45]) cube([50,3,50]);
                    translate([-25,-25,-65]) cube([3,65,70]);
                };
                translate([-50,-30,-130]) rotate([0,0,0]) cube([100,100,100]);
                translate([0,0, -50]) rotate([0,0,0]) cylinder(d=25, h=100);
            };
            translate([-25,8,-66]) cube([3,32,89]);

        };
        translate([-30, 14,-55]) rotate([0,90,0]) cylinder(d=5, h=10);
        translate([-30,34,-55]) rotate([0,90,0]) cylinder(d=5, h=10);
        translate([-30,34,-25]) rotate([0,90,0]) cylinder(d=5, h=10);
        translate([-30,34, 17]) rotate([0,90,0]) cylinder(d=5, h=10);
        translate([-30, 14, 17]) rotate([0,90,0]) cylinder(d=5, h=10);
        translate([15.5, 15.5, -5]) rotate([0,0,0]) cylinder(d=3, h=12);
        translate([15.5, -15.5, -5]) rotate([0,0,0]) cylinder(d=3, h=12);
        translate([-15.5, 15.5, -5]) rotate([0,0,0]) cylinder(d=3, h=12);
        translate([-15.5, -15.5, -5]) rotate([0,0,0]) cylinder(d=3, h=12);

    }
}

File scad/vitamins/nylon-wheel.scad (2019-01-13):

wheel_23mm   = ["Nylon Wheel 23 mm", 7.8, 7.4, 14, 5, 7, 5, 17.5];
wheel_34mm   = ["Nylon Wheel 34.5 mm", 12.25, 12, 19, 6, 11, 6, 25];

function wheel_type(type) = type[0];
function wheel_circle_offset(type) = type[1];
function wheel_circle_diameter(type) = type[2];
function wheel_bearing_od(type) = type[3];
function wheel_bearing_height(type) = type[4];
function wheel_width(type) = type[5];
function wheel_bearing_id(type) = type[6];
function wheel_v_slot_offset(type) = type[7];

module nylon_wheel(type)
{
    color("LightGrey",.9)
    difference()
    {
        union()
        {
            rotate_extrude(convexity = 10, $fn = 64)
            translate([wheel_circle_offset(type), 0, 0])
            circle(d = wheel_circle_diameter(type), $fn = 64);
            cylinder(d=wheel_bearing_od(type), h=wheel_bearing_height(type), center=true);
        }
        translate([0,0,wheel_width(type)/2])
        cylinder(d=50,h=10);
        translate([0,0,-10 - wheel_width(type)/2])
        cylinder(d=50,h=10);
        cylinder(d=wheel_bearing_id(type),h=10,center=true,$fn=24);
    }
}

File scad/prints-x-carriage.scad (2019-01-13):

include <x-carriage-plate.scad>

translate([0,0,21.5]) rotate([180,0,0]) x_carriage_plate(14, 17.5, 2.5);
//translate([0,80,21.5]) rotate([180,0,0]) x_carriage_plate(14, 17.5, 2.5);

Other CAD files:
freecad/vitamins/tcst2103.FCStd
freecad/steppers_board_mount.FCStd
freecad/vitamins/gp1s51.FCStd
freecad/titan_mount_plate.FCStd
scad/prints-x-end.scad
freecad/left_y_idler_plate.FCStd
freecad/vitamins/coupler.FCStd
freecad/x_carriage_plate.FCStd
scad/prints-y-corners.scad
scad/top.scad
scad/vitamins/ball-bearings.scad
scad/vitamins/bars.scad
scad/vitamins/belts.scad
scad/vitamins/bulldog.scad
scad/vitamins/cable_strip.scad
scad/vitamins/colors.scad
scad/vitamins/components.scad
scad/vitamins/d-connectors.scad
scad/vitamins/e3d_hot_end.scad
scad/vitamins/electronics.scad
scad/vitamins/extruders.scad
scad/vitamins/fans.scad
scad/vitamins/hot_ends.scad
scad/vitamins/jhead_hot_end.scad
scad/vitamins/light_strips.scad
scad/vitamins/linear-bearings.scad
scad/vitamins/m90_hot_end.scad
scad/vitamins/microswitch.scad
scad/vitamins/nuts.scad
scad/vitamins/o_rings.scad
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

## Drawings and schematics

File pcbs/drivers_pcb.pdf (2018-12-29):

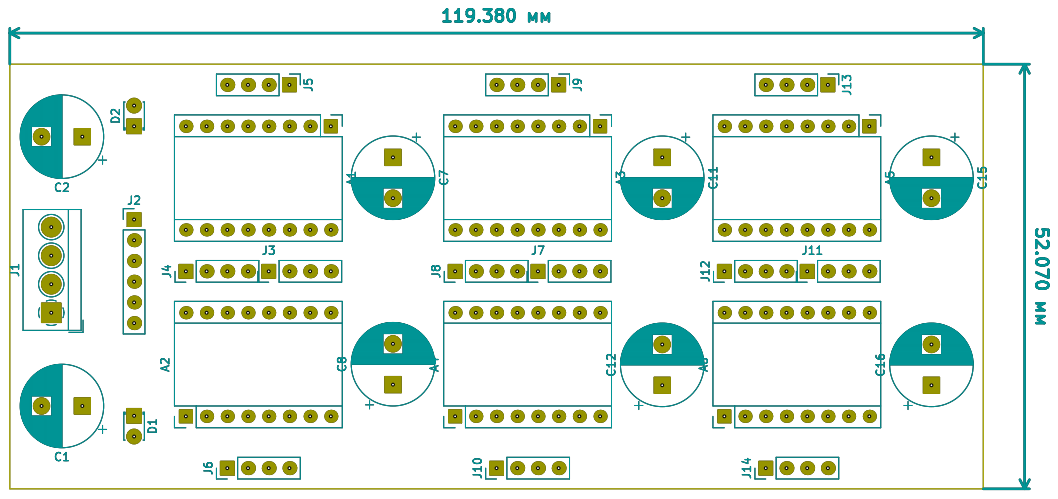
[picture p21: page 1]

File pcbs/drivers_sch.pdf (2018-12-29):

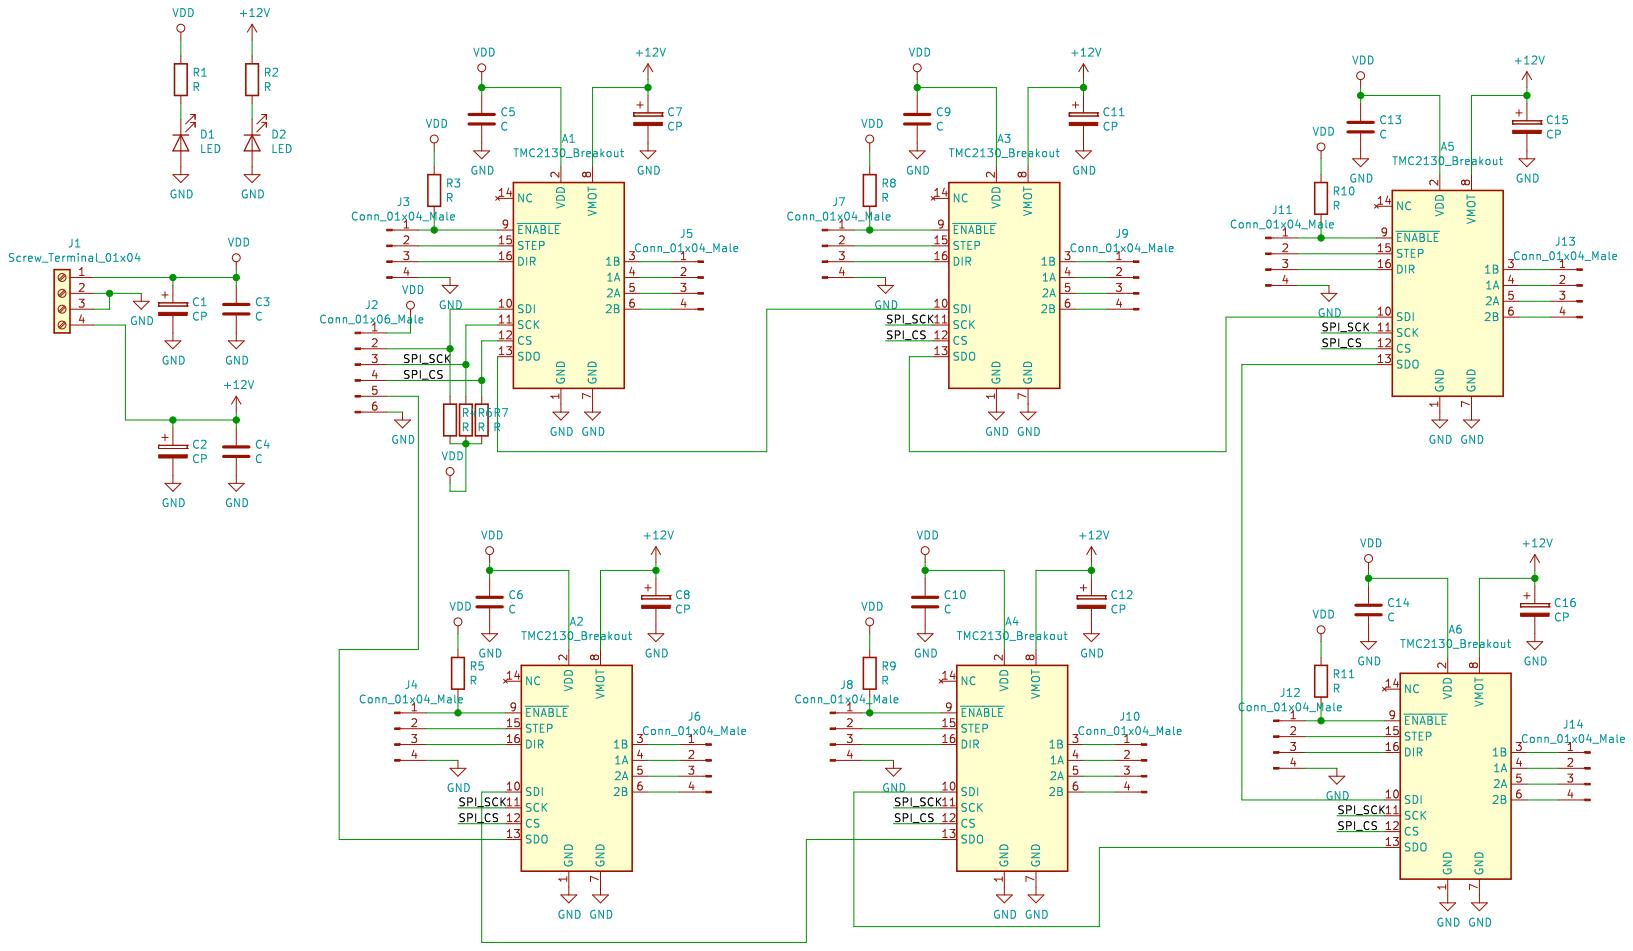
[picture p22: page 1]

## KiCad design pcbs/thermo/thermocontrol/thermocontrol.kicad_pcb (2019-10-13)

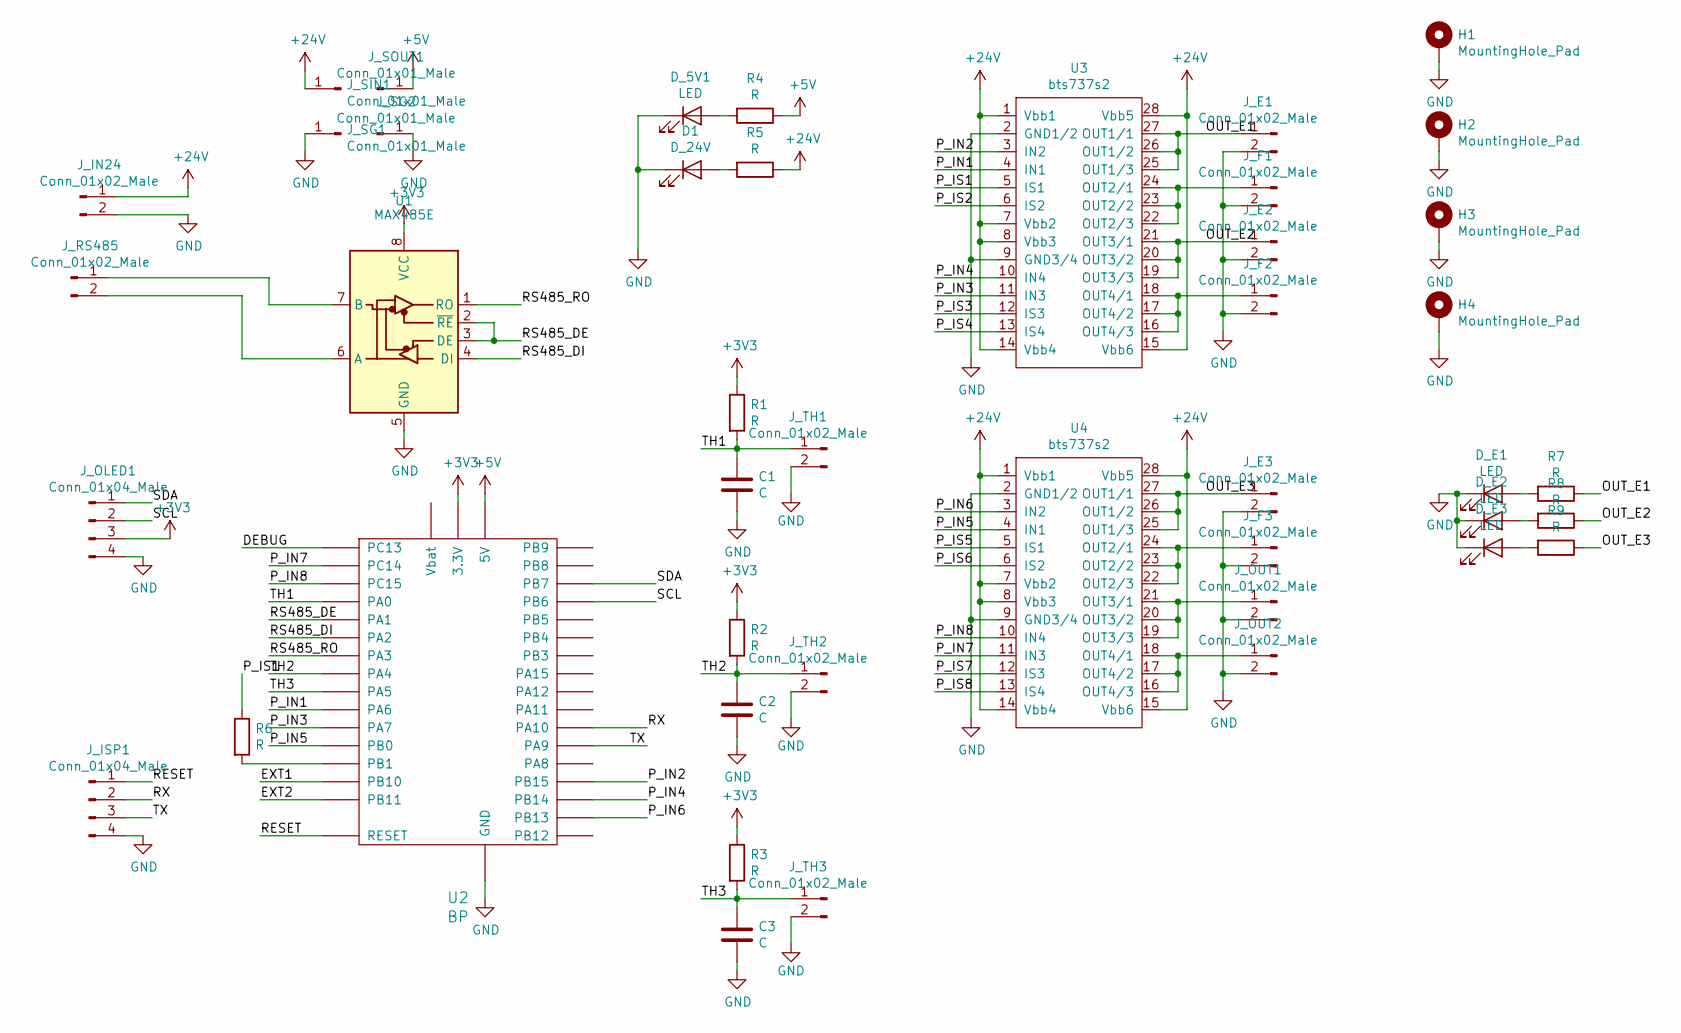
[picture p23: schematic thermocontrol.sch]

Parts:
C1, C2, C3: C; C_0805_2012Metric
D1: D_24V; LED_0805_2012Metric
D_5V1: LED; LED_0805_2012Metric
D_E1, D_E2, D_E3: LED; LED_0805_2012Metric
H1, H2, H3, H4: MountingHole_Pad; MountingHole_3.2mm_M3_DIN965_Pad
J_E1, J_E2, J_E3: Conn_01x02_Male; TerminalBlock_MetzConnect_Type011_RT05502HBWC_1x02_P5.00mm_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
J_F1, J_F2, J_F3: Conn_01x02_Male; PinHeader_1x02_P2.54mm_Vertical
J_IN24: Conn_01x02_Male; TerminalBlock_MetzConnect_Type011_RT05502HBWC_1x02_P5.00mm_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
J_ISP1: Conn_01x04_Male; PinHeader_2x02_P2.54mm_Vertical
J_OLED1: Conn_01x04_Male; PinHeader_2x02_P2.54mm_Vertical
J_OUT1, J_OUT2: Conn_01x02_Male; PinHeader_1x02_P2.54mm_Vertical
J_RS485: Conn_01x02_Male; PinHeader_1x02_P2.54mm_Vertical
J_SG1, J_SG2: Conn_01x01_Male; PinHeader_1x01_P2.54mm_Vertical
J_SIN1: Conn_01x01_Male; PinHeader_1x01_P2.54mm_Vertical
J_SOUT1: Conn_01x01_Male; PinHeader_1x01_P2.54mm_Vertical
J_TH1, J_TH2, J_TH3: Conn_01x02_Male; PinHeader_1x02_P2.54mm_Vertical
R1, R2, R3, R4, R5, R6, R7, R8, R9: R; R_0805_2012Metric
U1: MAX485E; SOIC-8_3.9x4.9mm_P1.27mm
U2: BP; BLUEPILL1
U3, U4: bts737s2; SOIC-28W_7.5x18.7mm_P1.27mm

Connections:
+3V3: J_OLED1.3, R1.1, R2.1, R3.1, U1.8 (VCC), U2.3V3 (3.3V)
+5V: J_SOUT1.1, R4.1, U2.5V
+24V: J_IN24.1, J_SIN1.1, R5.1, U3.1 (Vbb1), U3.7 (Vbb2), U3.8 (Vbb3), U3.14 (Vbb4), U3.15 (Vbb6), U3.28 (Vbb5), U4.1 (Vbb1), U4.7 (Vbb2), U4.8 (Vbb3), U4.14 (Vbb4), U4.15 (Vbb6), U4.28 (Vbb5)
/DEBUG: U2.PC13
/EXT1: U2.PB10
/EXT2: U2.PB11
/OUT_E1: J_E1.1, R7.1, U3.25 (OUT1/3), U3.26 (OUT1/2), U3.27 (OUT1/1)
/OUT_E2: J_E2.1, R8.1, U3.19 (OUT3/3), U3.20 (OUT3/2), U3.21 (OUT3/1)
/OUT_E3: J_E3.1, R9.1, U4.25 (OUT1/3), U4.26 (OUT1/2), U4.27 (OUT1/1)
/P_IN1: U2.PA6, U3.4 (IN1)
/P_IN2: U2.PB15, U3.3 (IN2)
/P_IN3: U2.PA7, U3.11 (IN3)
/P_IN4: U2.PB14, U3.10 (IN4)
/P_IN5: U2.PB0, U4.4 (IN1)
/P_IN6: U2.PB13, U4.3 (IN2)
/P_IN7: U2.PC14, U4.11 (IN3)
/P_IN8: U2.PC15, U4.10 (IN4)
/P_IS1: R6.1, U3.5 (IS1)
/P_IS2: U3.6 (IS2)
/P_IS3: U3.12 (IS3)
/P_IS4: U3.13 (IS4)
/P_IS5: U4.5 (IS1)
/P_IS6: U4.6 (IS2)
/P_IS7: U4.12 (IS3)
/P_IS8: U4.13 (IS4)
/RESET: J_ISP1.1, U2.NRST (RESET)
/RS485_DE: U1.2 (~RE), U1.3 (DE), U2.PA1
/RS485_DI: U1.4 (DI), U2.PA2
/RS485_RO: U1.1 (RO), U2.PA3
/RX: J_ISP1.2, U2.PA10
/SCL: J_OLED1.2, U2.PB6
/SDA: J_OLED1.1, U2.PB7
/TH1: C1.1, J_TH1.1, R1.2, U2.PA0
/TH2: C2.1, J_TH2.1, R2.2, U2.PA4
/TH3: C3.1, J_TH3.1, R3.2, U2.PA5
/TX: J_ISP1.3, U2.PA9
GND: C1.2, C2.2, C3.2, D1.1 (K), D_5V1.1 (K), D_E1.1 (K), D_E2.1 (K), D_E3.1 (K), H1.1, H2.1, H3.1, H4.1, J_E1.2, J_E2.2, J_E3.2, J_F1.2, J_F2.2, J_F3.2, J_IN24.2, J_ISP1.4, J_OLED1.4, J_OUT1.2, J_OUT2.2, J_SG1.1, J_SG2.1, J_TH1.2, J_TH2.2, J_TH3.2, U1.5 (GND), U2.G (GND), U3.2 (GND1/2), U3.9 (GND3/4), U4.2 (GND1/2), U4.9 (GND3/4)
unnamed: D1.2 (A), R5.2
unnamed: D_5V1.2 (A), R4.2
unnamed: D_E1.2 (A), R7.2
unnamed: D_E2.2 (A), R8.2
unnamed: D_E3.2 (A), R9.2
unnamed: J_F1.1, U3.22 (OUT2/3), U3.23 (OUT2/2), U3.24 (OUT2/1)
unnamed: J_F2.1, U3.16 (OUT4/3), U3.17 (OUT4/2), U3.18 (OUT4/1)
unnamed: J_F3.1, U4.22 (OUT2/3), U4.23 (OUT2/2), U4.24 (OUT2/1)
unnamed: J_OUT1.1, U4.19 (OUT3/3), U4.20 (OUT3/2), U4.21 (OUT3/1)
unnamed: J_OUT2.1, U4.16 (OUT4/3), U4.17 (OUT4/2), U4.18 (OUT4/1)
unnamed: J_RS485.1, U1.7 (B)
unnamed: J_RS485.2, U1.6 (A)
unnamed: R6.2, U2.PB1

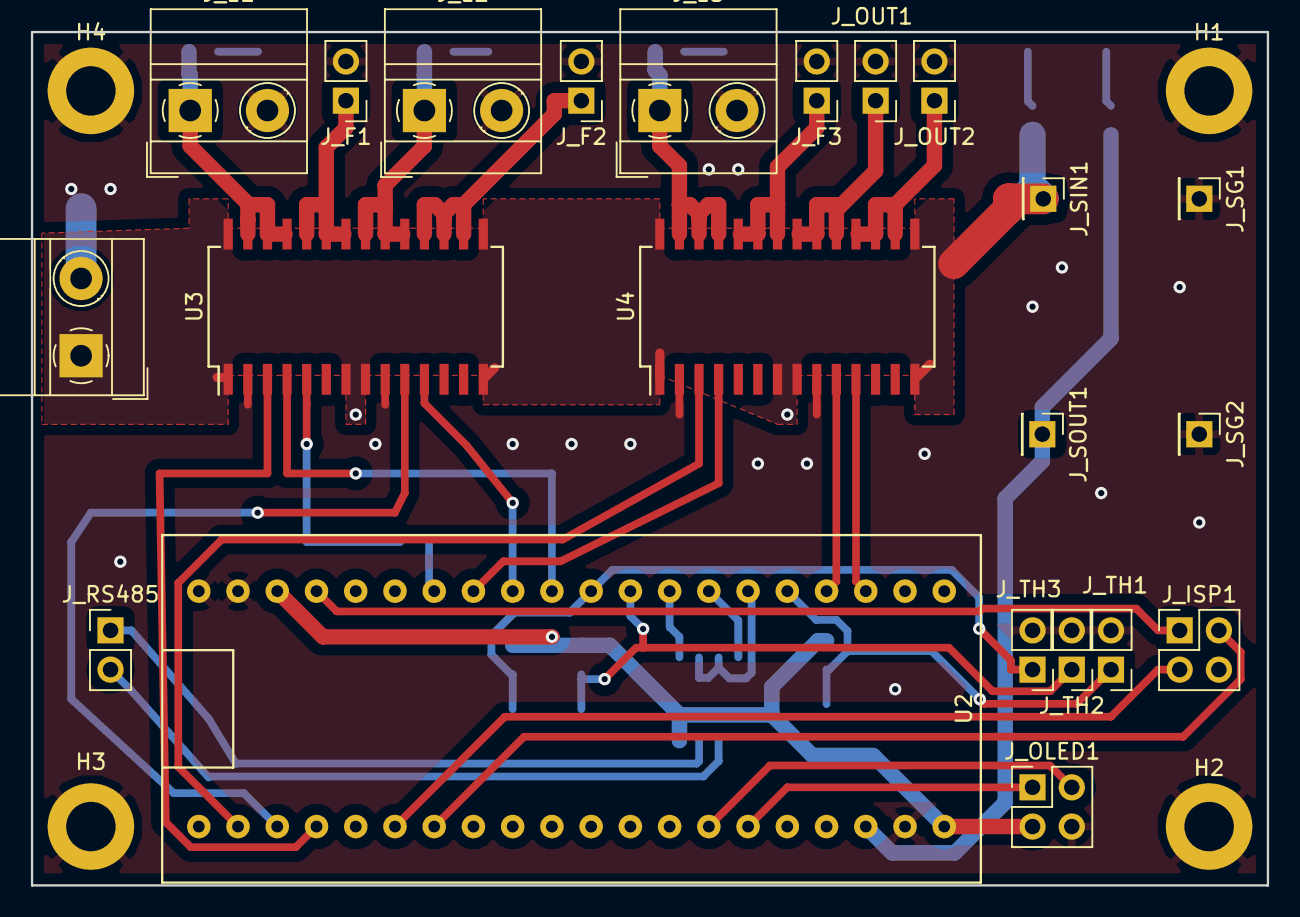
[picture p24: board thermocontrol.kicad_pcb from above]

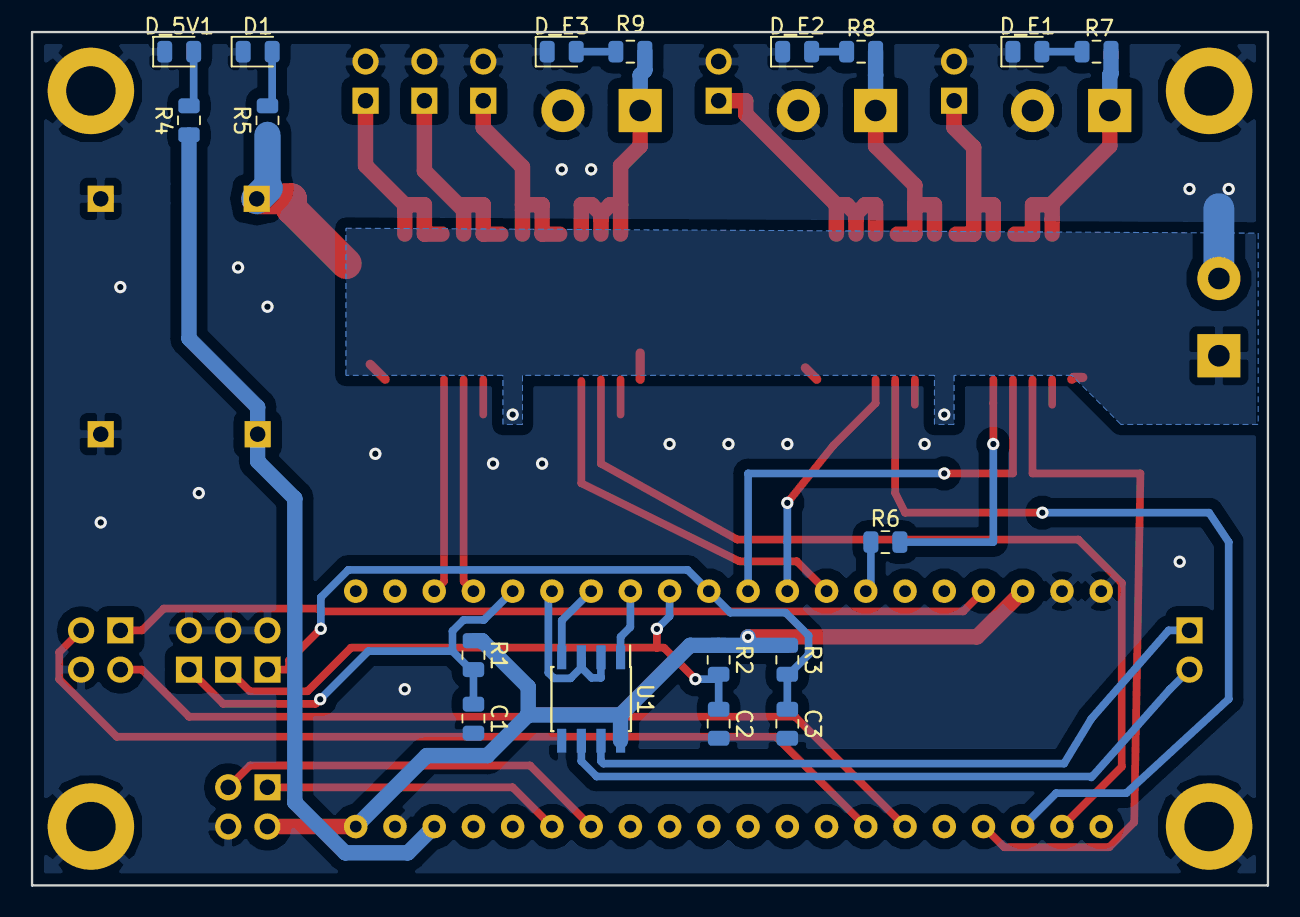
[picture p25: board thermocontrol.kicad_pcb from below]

Board: 2 copper layers, 80.0 x 55.2 mm, 44 parts (18 on the bottom side), 40 nets.

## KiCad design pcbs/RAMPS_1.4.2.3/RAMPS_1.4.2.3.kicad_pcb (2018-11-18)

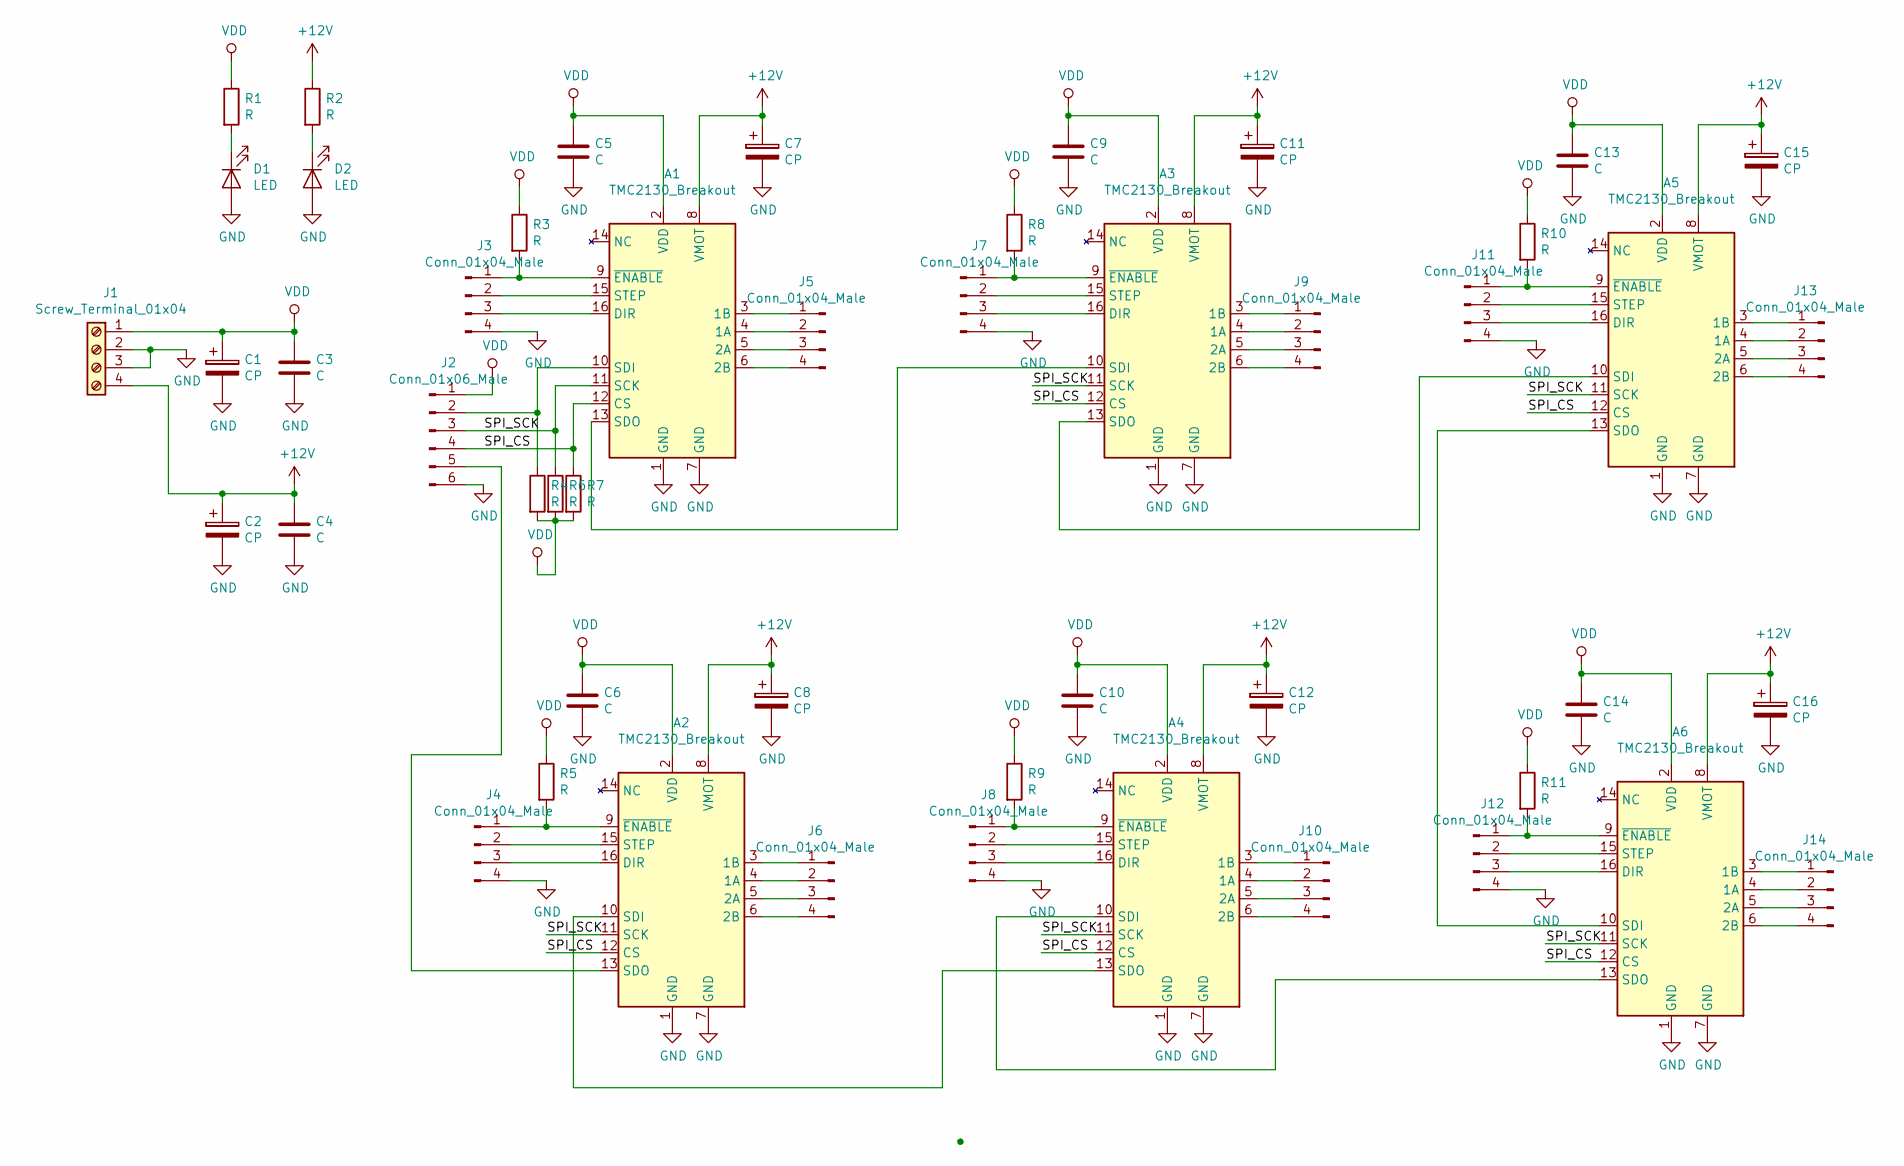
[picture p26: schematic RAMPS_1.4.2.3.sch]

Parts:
A1, A2, A3, A4, A5, A6: TMC2130_Breakout; Pololu_Breakout-16_15.2x20.3mm
C1, C2, C7, C8, C11, C12, C15, C16: CP; CP_Radial_D10.0mm_P5.00mm
C3, C4, C5, C6, C9, C10, C13, C14: C; C_0805_2012Metric
D1, D2: LED; LED_D1.8mm_W3.3mm_H2.4mm
J1: Screw_Terminal_01x04; TerminalBlock_4Ucon_1x04_P3.50mm_Horizontal
J2: Conn_01x06_Male; PinHeader_1x06_P2.54mm_Vertical
J3, J4, J5, J6, J7, J8, J9, J10, J11, J12, J13, J14: Conn_01x04_Male; PinHeader_1x04_P2.54mm_Vertical
R1, R2, R3, R4, R5, R6, R7, R8, R9, R10, R11: R; R_0805_2012Metric

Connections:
+12V: A1.8 (VMOT), A2.8 (VMOT), A3.8 (VMOT), A4.8 (VMOT), A5.8 (VMOT), A6.8 (VMOT), C2.1, C4.1, C7.1, C8.1, C11.1, C12.1, C15.1, C16.1, J1.4, R2.1
/SPI_CS: A1.12 (CS), A2.12 (CS), A3.12 (CS), A4.12 (CS), A5.12 (CS), A6.12 (CS), J2.4, R7.1
/SPI_SCK: A1.11 (SCK), A2.11 (SCK), A3.11 (SCK), A4.11 (SCK), A5.11 (SCK), A6.11 (SCK), J2.3, R6.1
GND: A1.1 (GND), A1.7 (GND), A2.1 (GND), A2.7 (GND), A3.1 (GND), A3.7 (GND), A4.1 (GND), A4.7 (GND), A5.1 (GND), A5.7 (GND), A6.1 (GND), A6.7 (GND), C1.2, C2.2, C3.2, C4.2, C5.2, C6.2, C7.2, C8.2, C9.2, C10.2, C11.2, C12.2, C13.2, C14.2, C15.2, C16.2, D1.2 (A), D2.2 (A), J1.2, J1.3, J2.6, J3.4, J4.4, J7.4, J8.4, J11.4, J12.4
unnamed: A1.3 (1B), J5.1
unnamed: A1.4 (1A), J5.2
unnamed: A1.5 (2A), J5.3
unnamed: A1.6 (2B), J5.4
unnamed: A1.9 (~ENABLE), J3.1, R3.2
unnamed: A1.10 (SDI), J2.2, R4.1
unnamed: A1.13 (SDO), A3.10 (SDI)
unnamed: A1.15 (STEP), J3.2
unnamed: A1.16 (DIR), J3.3
unnamed: A2.3 (1B), J6.1
unnamed: A2.4 (1A), J6.2
unnamed: A2.5 (2A), J6.3
unnamed: A2.6 (2B), J6.4
unnamed: A2.9 (~ENABLE), J4.1, R5.2
unnamed: A2.10 (SDI), A4.13 (SDO)
unnamed: A2.13 (SDO), J2.5
unnamed: A2.15 (STEP), J4.2
unnamed: A2.16 (DIR), J4.3
unnamed: A3.3 (1B), J9.1
unnamed: A3.4 (1A), J9.2
unnamed: A3.5 (2A), J9.3
unnamed: A3.6 (2B), J9.4
unnamed: A3.9 (~ENABLE), J7.1, R8.2
unnamed: A3.13 (SDO), A5.10 (SDI)
unnamed: A3.15 (STEP), J7.2
unnamed: A3.16 (DIR), J7.3
unnamed: A4.3 (1B), J10.1
unnamed: A4.4 (1A), J10.2
unnamed: A4.5 (2A), J10.3
unnamed: A4.6 (2B), J10.4
unnamed: A4.9 (~ENABLE), J8.1, R9.2
unnamed: A4.10 (SDI), A6.13 (SDO)
unnamed: A4.15 (STEP), J8.2
unnamed: A4.16 (DIR), J8.3
unnamed: A5.3 (1B), J13.1
unnamed: A5.4 (1A), J13.2
unnamed: A5.5 (2A), J13.3
unnamed: A5.6 (2B), J13.4
unnamed: A5.9 (~ENABLE), J11.1, R10.2
unnamed: A5.13 (SDO), A6.10 (SDI)
unnamed: A5.15 (STEP), J11.2
unnamed: A5.16 (DIR), J11.3
unnamed: A6.3 (1B), J14.1
unnamed: A6.4 (1A), J14.2
unnamed: A6.5 (2A), J14.3
unnamed: A6.6 (2B), J14.4
unnamed: A6.9 (~ENABLE), J12.1, R11.2
unnamed: A6.15 (STEP), J12.2
unnamed: A6.16 (DIR), J12.3
unnamed: D1.1 (K), R1.2
unnamed: D2.1 (K), R2.2
VDD: A1.2 (VDD), A2.2 (VDD), A3.2 (VDD), A4.2 (VDD), A5.2 (VDD), A6.2 (VDD), C1.1, C3.1, C5.1, C6.1, C9.1, C10.1, C13.1, C14.1, J1.1, J2.1, R1.1, R3.1, R4.2, R5.1, R6.2, R7.2, R8.1, R9.1, R10.1, R11.1

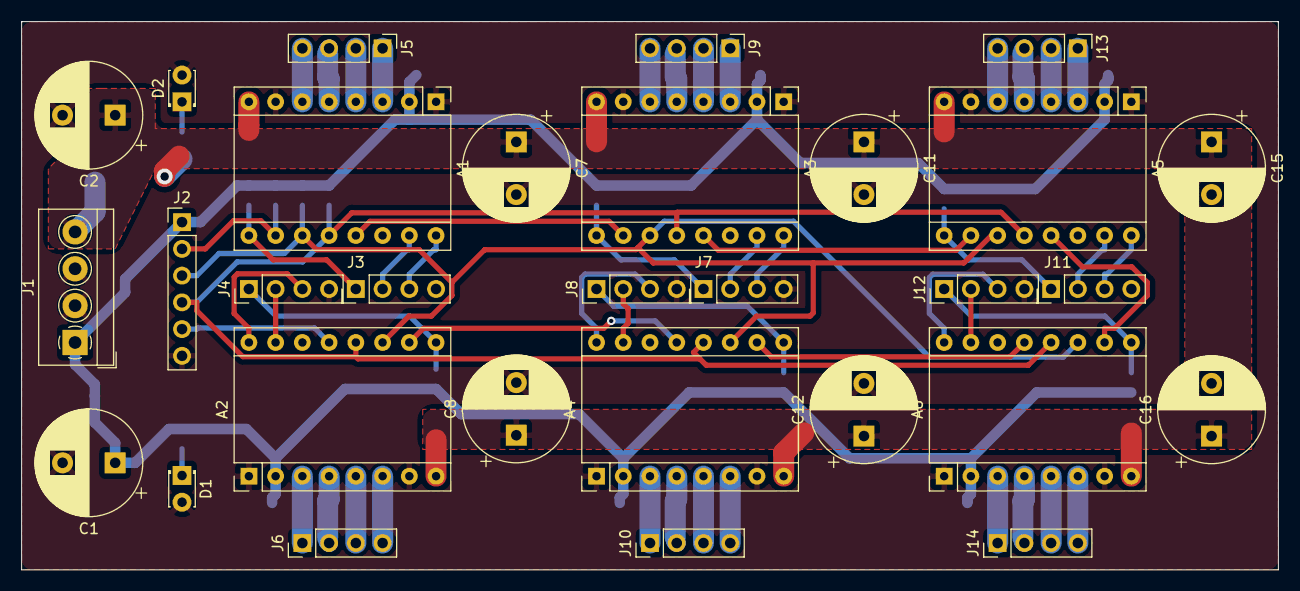
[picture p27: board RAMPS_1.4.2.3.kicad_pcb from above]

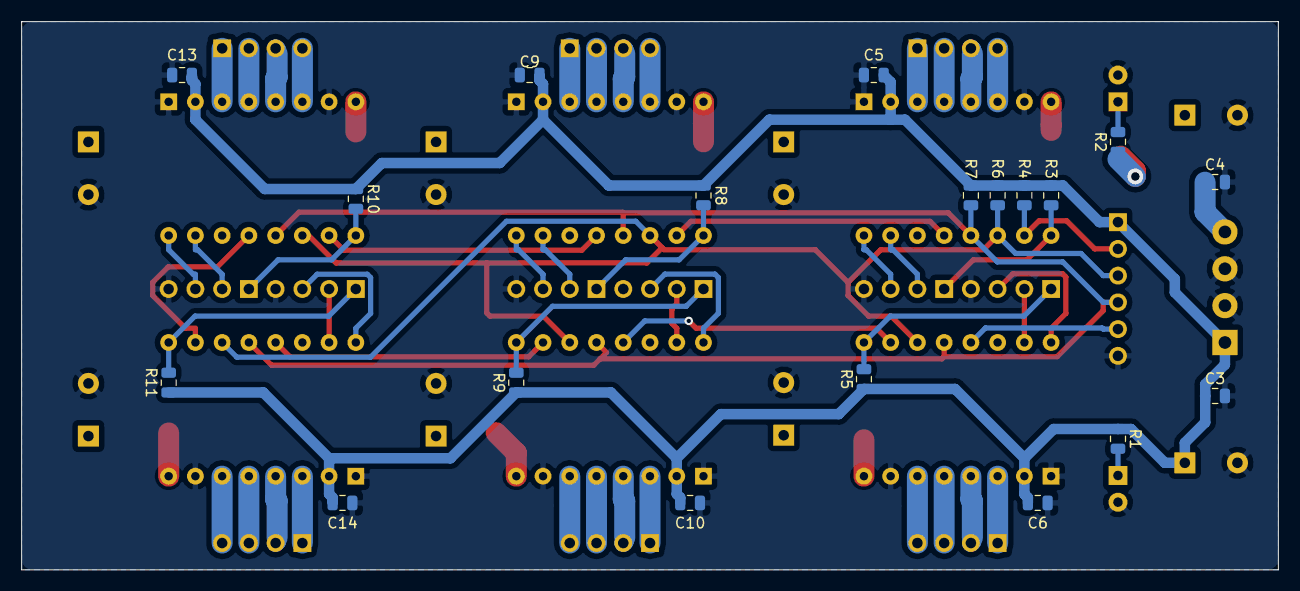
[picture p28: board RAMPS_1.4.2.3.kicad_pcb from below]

Board: 2 copper layers, 119.4 x 52.1 mm, 49 parts (19 on the bottom side), 56 nets.

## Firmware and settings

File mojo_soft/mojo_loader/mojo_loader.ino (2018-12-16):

/*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
    You should have received a copy of the GNU General Public License
    along with this program.  If not, see <http://www.gnu.org/licenses/>.
*/

#include "hardware.h"
#include <SPI.h>
#include "flash.h"
#include "cmdline.h"
#include "commands.h"
#include <stdio.h>


typedef enum {
  IDLE,
  READ_SIZE,
  WRITE_TO_FLASH,
  WRITE_TO_FPGA,
  VERIFY_FLASH,
  LOAD_FROM_FLASH
}
loaderState_t;

typedef enum {
  WAIT, START_LOAD, LOAD, SERVICE
}
taskState_t;

#if defined(__AVR_ATmega32U4__)   // Mojo V3
#define BUFFER_SIZE 1024
#define SERIAL_STOP 1000
#define SERIAL_CUT 1020
#elif defined(__AVR_ATmega16U4__) // Mojo V2
#define BUFFER_SIZE 512
#define SERIAL_STOP 500
#define SERIAL_CUT 510
#endif

uint8_t loadBuffer[BUFFER_SIZE + 128];

volatile taskState_t taskState = SERVICE;

/* This is where you should add your own code! Feel free to edit anything here.
   This function will work just like the Arduino loop() function in that it will
   be called over and over. You should try to not delay too long in the loop to
   allow the Mojo to enter loading mode when requested. */
void userLoop() {
  uartTask();
}

/* this is used to undo any setup you did in initPostLoad */
void disablePostLoad() {
  UCSR1B = 0; // disable serial port
  SPI.end();  // disable SPI
  SET(CCLK, LOW);
  OUT(PROGRAM);
  SET(PROGRAM, LOW); // reset the FPGA
  IN(INIT);
  SET(INIT, HIGH); // pullup on INIT
}

extern "C" void SerialPutC(uint8_t ch) {
  Serial.write(ch);
}

static FILE serialout = {0} ;

static int serial_putchar (char c, FILE *stream)
{
    if (c == '\n')
      Serial.write('\r');
    Serial.write(c) ;
    return 0 ;
}


/* Here you can do some setup before entering the userLoop loop */
void initPostLoad() {
  //Serial.flush();

  Serial1.begin(500000);
  
  // Setup all the SPI pins
  SET(CS_FLASH, HIGH);
  OUT(SS);
  SET(SS, HIGH);
  SPI_Setup(); // enable the SPI Port

  DDRD |= (1 << 3);
  DDRD &= ~(1 << 2);
  PORTD |= (1 << 2);

  // This pin is used to signal the serial buffer is almost full
  OUT(TX_BUSY);
  SET(TX_BUSY, LOW);

  // set progam as an input so that it's possible to use a JTAG programmer with the Mojo
  SET(PROGRAM, HIGH);
  IN(PROGRAM);

  // the FPGA looks for CCLK to be high to know the AVR is ready for data
  SET(CCLK, HIGH);
  IN(CCLK); // set as pull up so JTAG can work
  SET(DONE, HIGH);
  IN(DONE);
  SET(INIT, HIGH);
  IN(INIT);

  fdev_setup_stream (&serialout, serial_putchar, NULL, _FDEV_SETUP_WRITE);

  // The uart is the standard output device STDOUT.
  stdout = &serialout;

  //cmdlineSetOutputFunc(SerialPutC);
  cmdlineInit();
  setup_commands();
  cmdlinePrintPrompt();
}

void setup() {
  /* Disable clock division */
  clock_prescale_set(clock_div_1);

  OUT(CS_FLASH);
  SET(CS_FLASH, HIGH);
  OUT(CCLK);
  OUT(PROGRAM);

  /* Disable digital inputs on analog pins */
  DIDR0 = 0xF3;
  DIDR2 = 0x03;

  Serial.begin(115200); // Baud rate does nothing

  sei(); // enable interrupts

  getDevID();
  loadFromFlash(); // load on power up
  initPostLoad();
}

void loop() {
  static loaderState_t state = IDLE;
  static int8_t destination;
  static int8_t verify;
  static uint32_t byteCount;
  static uint32_t transferSize;

  int16_t w;
  uint8_t bt;
  uint8_t buffIdx;
  uint32_t addr;

  switch (taskState) {
    case WAIT:
      break;
    case START_LOAD: // command to enter loader mode
      disablePostLoad(); // setup peripherals
      taskState = LOAD; // enter loader mode
      state = IDLE; // in idle state
      break;
    case LOAD:
      w = Serial.read();
      bt = (uint8_t) w;
      if (w >= 0) { // if we have data
        switch (state) {
          case IDLE: // in IDLE we are waiting for a command from the PC
            byteCount = 0;
            transferSize = 0;
            if (bt == 'F') { // write to flash
              destination = 0; // flash
              verify = 0; // don't verify
              state = READ_SIZE;
              Serial.write('R'); // signal we are ready
            }
            if (bt == 'V') { // write to flash and verify
              destination = 0; // flash
              verify = 1; // verify
              state = READ_SIZE;
              Serial.write('R'); // signal we are ready
            }
            if (bt == 'R') { // write to RAM
              destination = 1; // ram
              state = READ_SIZE;
              Serial.write('R'); // signal we are ready
            }
            if (bt == 'E') { //erase
              eraseFlash();
              Serial.write('D'); // signal we are done
            }
            //Serial.flush();
            break;
          case READ_SIZE: // we need to read in how many bytes the config data is
            transferSize |= ((uint32_t) bt << (byteCount++ * 8));
            if (byteCount > 3) {
              byteCount = 0;
              
              if (destination) {
                state = WRITE_TO_FPGA;
                initLoad(); // get the FPGA ready for a load
                startLoad(); // start the load
              }
              else {
                buffIdx = 0;
                state = WRITE_TO_FLASH;
                eraseFlash();
              }
              Serial.write('O'); // signal the size was read
              //Serial.flush();
            }
            break;
          case WRITE_TO_FLASH:
            if (byteCount < 256 - 5)
              buffIdx = byteCount % 256;
            else
              buffIdx = (byteCount+5) % 256;
            loadBuffer[buffIdx] = bt;
            addr = byteCount + 5;
            byteCount++;

            if (addr % 256 == 255 || byteCount == transferSize){
              writeFlash(addr - buffIdx, loadBuffer, buffIdx+1); // write blocks of 256 bytes at a time for speed
            }

            if (byteCount == transferSize) { // the last block to write
              delayMicroseconds(50); // these are necciary to get reliable writes
              uint32_t size = byteCount + 5;
              for (uint8_t k = 0; k < 4; k++) {
                writeByteFlash(k + 1, (size >> (k * 8)) & 0xFF); // write the size of the config data to the flash
                delayMicroseconds(50);
              }
              delayMicroseconds(50);
              writeByteFlash(0, 0xAA); // 0xAA is used to signal the flash has valid data
              Serial.write('D'); // signal we are done
              //Serial.flush(); // make sure it sends
              if (verify) {
                state = VERIFY_FLASH;
              }
              else {
                state = LOAD_FROM_FLASH;
              }
            }
            break;
          case WRITE_TO_FPGA:
            sendByte(bt); // just send the byte!
            if (++byteCount == transferSize) { // if we are done
              sendExtraClocks(); // send some extra clocks to make sure the FPGA is happy
              state = IDLE;
              taskState = SERVICE; // enter user mode
              initPostLoad();
              Serial.write('D'); // signal we are done
              //Serial.flush();
            }
            break;
          case VERIFY_FLASH:
            if (bt == 'S') {
              byteCount += 5;
              for (uint32_t k = 0; k < byteCount; k += 256) { // dump all the flash data
                uint16_t s;
                if (k + 256 <= byteCount) {
                  s = 256;
                }
                else {
                  s = byteCount - k;
                }
                readFlash(loadBuffer, k, s); // read blocks of 256
                uint16_t br = Serial.write((uint8_t*) loadBuffer, s); // dump them to the serial port
                k -= (256 - br); // if all the bytes weren't sent, resend them next round
                //Serial.flush();
                delay(10); // needed to prevent errors in some computers running Windows (give it time to process the data?)
              }
              state = LOAD_FROM_FLASH;
            }
            break;
          case LOAD_FROM_FLASH:
            if (bt == 'L') {
              loadFromFlash(); // load 'er up!
              Serial.write('D'); // loading done
              //Serial.flush();
              state = IDLE;
              taskState = SERVICE;
              initPostLoad();
            }
            break;
        }
      }

      break;
    case SERVICE:
      userLoop(); // loop the user code
      break;
  }
}

/* This is called when any control lines on the serial port are changed.
 It requires a modification to the Arduino core code to work.

 This looks for 5 pulses on the DTR line within 250ms. Checking for 5
 makes sure that false triggers won't happen when the serial port is opened. */
void lineStateEvent(unsigned char linestate)
{
  static unsigned long start = 0;
  static uint8_t falling = 0;
  if (!(linestate & LINESTATE_DTR)) {
    if ((millis() - start) < 250) {
      if (++falling >= 5)
        taskState = START_LOAD;
    }
    else {
      start = millis();
      falling = 1;
    }
  }
}


/* This function handles all the serial to USB work. It works
   much the same way as the ADC task, but it just forwards data
   from one port to the other instead of the ADC to the FPGA. */
void uartTask() {
  if (Serial) { // does the data have somewhere to go?
    int16_t w;
    while ((w = Serial.read()) >= 0) {
      cmdlineInputFunc((uint8_t)w);
      cmdlineMainLoop();
    }
  }
}

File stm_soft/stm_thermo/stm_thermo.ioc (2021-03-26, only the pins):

Mcu.UserName=STM32F103C8Tx
PA0-WKUP.GPIO_Label=ADC_TH1
PA0-WKUP.Signal=ADCx_IN0
PA1.GPIO_Label=RS485_DE
PA1.Signal=GPIO_Output
PA10.Signal=USART1_RX
PA13.Signal=SYS_JTMS-SWDIO
PA14.Signal=SYS_JTCK-SWCLK
PA15.GPIO_Label=SPI1_NSS
PA15.Signal=GPIO_Output
PA2.GPIO_Label=RS485_TX
PA2.Signal=USART2_TX
PA3.GPIO_Label=RS485_RX
PA3.Signal=USART2_RX
PA4.GPIO_Label=ADC_TH2
PA4.Signal=ADCx_IN4
PA5.GPIO_Label=ADC_TH3
PA5.Signal=ADCx_IN5
PA6.GPIO_Label=TIM3_CH1_E1
PA6.Signal=S_TIM3_CH1
PA7.GPIO_Label=TIM3_CH2_E2
PA7.Signal=S_TIM3_CH2
PA9.Signal=USART1_TX
PB0.GPIO_Label=TIM3_CH3_E3
PB0.Signal=S_TIM3_CH3
PB13.GPIO_Label=TIM1_CH1N_F3
PB13.Signal=TIM1_CH1N
PB14.GPIO_Label=TIM1_CH2N_F2
PB14.Signal=TIM1_CH2N
PB15.GPIO_Label=TIM1_CH3N_F1
PB15.Signal=TIM1_CH3N
PB3.Signal=SPI1_SCK
PB4.Signal=SPI1_MISO
PB5.Signal=SPI1_MOSI
PC13-TAMPER-RTC.GPIO_Label=DEBUG_LED
PC13-TAMPER-RTC.Signal=GPIO_Output
PC14-OSC32_IN.GPIO_Label=EXT1_ON
PC14-OSC32_IN.Signal=GPIO_Output
PC15-OSC32_OUT.GPIO_Label=EXT2_ON
PC15-OSC32_OUT.Signal=GPIO_Output
PD0-OSC_IN.Signal=RCC_OSC_IN
PD1-OSC_OUT.Signal=RCC_OSC_OUT

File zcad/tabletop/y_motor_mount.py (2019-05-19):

from connectors import Connector, Shape, Unit, VisualConnector
from pyservoce.libservoce import Color
from zencad import box, cylinder, deg, linear_extrude, point3, polygon, unify


def gen_y_motor_mount(
    front_vslot, left_motor, left_rail, left_vslot, parts, vc_prefix, is_right=False
):
    pose = {}
    if is_right:
        front_slot_end = "top"
        left_slot_side = "right"
    else:
        front_slot_end = "bottom"
        left_slot_side = "left"

    pose["mount_plane"] = front_vslot.get_connector("{}, right2".format(front_slot_end))
    pose["top_plane"] = front_vslot.get_connector("{}, front".format(front_slot_end))
    pose["bottom_plane"] = front_vslot.get_connector("{}, back".format(front_slot_end))
    pose["left_plane"] = left_vslot.get_connector("bottom, {}".format(left_slot_side))
    pose["rail_top_plane"] = left_rail.get_connector("front")
    pose["mount_holes_1"] = front_vslot.get_connector(
        ("{}, right".format(front_slot_end), 10)
    )
    pose["mount_holes_2"] = front_vslot.get_connector(
        ("{}, right2".format(front_slot_end), 10)
    )
    pose["mount_hole_3"] = front_vslot.get_connector(
        ("{}, right2".format(front_slot_end), -10)
    )
    pose["motor_bottom"] = left_motor.get_connector("bottom")
    pose["motor_top"] = left_motor.get_connector("top")
    for i in range(4):
        pose[("motor_mount_hole", i)] = left_motor.get_connector(("mount_hole", i))
    if 0:
        for n, c in pose.items():
            vcn = vc_prefix + str(n)
            vc = VisualConnector().place(pose={"origin": c}, config={"text": str(n)})
            parts.append([vcn, vc])
    for k, v in pose.items():
        if k not in ["motor_top"]:
            pose[k] = v.replace(use_for_solve=False)
    left_y_motor_mount = LeftYMotorMount().place(
        pose=pose, config={"motor_body_size": left_motor.unit.body_size}
    )
    return left_y_motor_mount


class LeftYMotorMount(Unit):
    motor_hole_spacing = 0.5
    base_thickness = 5
    base_plate_extra_length = 20

    def shapes(self, config=None):
        motor_body_size = config["motor_body_size"]
        left_x = config["left_plane"].position.x
        rail_z = config["rail_top_plane"].position.z
        top_z = config["top_plane"].position.z
        bottom_z = config["bottom_plane"].position.z
        base_y = config["mount_plane"].position.y
        motor_center_y = config["motor_top"].position.y
        motor_center_z = config["motor_top"].position.z

        if base_y < 0:
            left_right_c = -1
            right_c = 1
            left_c = 0
        else:
            left_right_c = 1
            right_c = 0
            left_c = 1

        motor_hole_left_x = config["motor_top"].position.x
        motor_hole_right_x = config["motor_bottom"].position.x + self.base_thickness
        motor_hole_back_y = (
            motor_center_y
            + (motor_body_size / 2 + self.motor_hole_spacing) * left_right_c
        )
        motor_hole_front_y = (
            motor_center_y
            - (motor_body_size / 2 + self.motor_hole_spacing) * left_right_c
        )
        motor_hole_top_z = (
            motor_center_z + motor_body_size / 2 + self.motor_hole_spacing
        )
        motor_hole_bottom_z = (
            motor_center_z - motor_body_size / 2 - self.motor_hole_spacing
        )
        base_plate_top_z = motor_hole_top_z + self.base_thickness
        base_plate_right_x = motor_hole_right_x + self.base_plate_extra_length
        motor_depth = config["motor_bottom"].position.x - config["motor_top"].position.x
        motor_hole_depth = motor_depth * 0.7
        motor_hole_width = motor_body_size + self.motor_hole_spacing * 2
        print("base_y", base_y)
        print("back_y", motor_hole_back_y)
        print("front_y", motor_hole_front_y)

        base_plate_height = abs(base_y - motor_hole_back_y)

        base_plate = (
            linear_extrude(
                polygon(
                    [
                        [left_x, bottom_z],
                        [left_x, base_plate_top_z],
                        [motor_hole_right_x, base_plate_top_z],
                        [base_plate_right_x, top_z],
                        [base_plate_right_x, bottom_z],
                        [left_x, bottom_z],
                    ]
                ).fillet(1.5),
                base_plate_height,
            )
            .rotateX(deg(90))
            .translate(0, base_y + base_plate_height * right_c, 0)
        )

        motor_hole = box(
            motor_hole_depth + 1, motor_hole_width, motor_hole_width
        ).translate(
            motor_hole_left_x,
            motor_hole_front_y - motor_hole_width * right_c,
            motor_hole_bottom_z,
        )

        motor_box = (
            box(
                motor_hole_depth + self.base_thickness,
                motor_hole_width + self.base_thickness + 1,
                motor_hole_width + self.base_thickness * 2,
            ).translate(
                motor_hole_left_x - self.base_thickness,
                motor_hole_front_y
                - self.base_thickness * left_right_c
                - (motor_hole_width + self.base_thickness + 1) * right_c,
                motor_hole_bottom_z - self.base_thickness,
            )
            - motor_hole
            - cylinder(r=13, h=self.base_thickness + 2)
            .rotateY(deg(90))
            .translate(
                motor_hole_left_x - self.base_thickness - 1,
                motor_center_y,
                motor_center_z,
            )
        )
        for i in range(4):
            hole_pos = config[("motor_mount_hole", i)].position
            motor_box -= (
                cylinder(r=2, h=self.base_thickness + 2)
                .rotateY(deg(-90))
                .translate(hole_pos.x - 1, hole_pos.y, hole_pos.z)
            )

        base_plate += motor_box

        h1_1 = config["mount_holes_1"].position
        h1_2 = point3(
            base_plate_right_x - self.base_plate_extra_length / 2, h1_1.y, h1_1.z
        )
        h2_1 = config["mount_holes_2"].position
        h2_2 = point3(
            base_plate_right_x - self.base_plate_extra_length / 2, h2_1.y, h2_1.z
        )
        for pos in [config["mount_hole_3"].position, h1_1, h1_2, h2_1, h2_2]:
            base_plate -= (
                cylinder(r=2.5, h=self.base_thickness + 2)
                .rotateX(deg(90))
                .translate(pos.x, pos.y + 1 + self.base_thickness * right_c, pos.z)
            )

        return [Shape(unify(base_plate), Color(0.7, 0.7, 0))]

    def finalize_config(self, config, localized_connectors):
        finalized_config = {}
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

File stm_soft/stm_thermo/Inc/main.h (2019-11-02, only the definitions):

#define DEBUG_LED_Pin GPIO_PIN_13
#define DEBUG_LED_GPIO_Port GPIOC
#define EXT1_ON_Pin GPIO_PIN_14
#define EXT1_ON_GPIO_Port GPIOC
#define EXT2_ON_Pin GPIO_PIN_15
#define EXT2_ON_GPIO_Port GPIOC
#define ADC_TH1_Pin GPIO_PIN_0
#define ADC_TH1_GPIO_Port GPIOA
#define RS485_DE_Pin GPIO_PIN_1
#define RS485_DE_GPIO_Port GPIOA
#define RS485_TX_Pin GPIO_PIN_2
#define RS485_TX_GPIO_Port GPIOA
#define RS485_RX_Pin GPIO_PIN_3
#define RS485_RX_GPIO_Port GPIOA
#define ADC_TH2_Pin GPIO_PIN_4
#define ADC_TH2_GPIO_Port GPIOA
#define ADC_TH3_Pin GPIO_PIN_5
#define ADC_TH3_GPIO_Port GPIOA
#define TIM3_CH1_E1_Pin GPIO_PIN_6
#define TIM3_CH1_E1_GPIO_Port GPIOA
#define TIM3_CH2_E2_Pin GPIO_PIN_7
#define TIM3_CH2_E2_GPIO_Port GPIOA
#define TIM3_CH3_E3_Pin GPIO_PIN_0
#define TIM3_CH3_E3_GPIO_Port GPIOB
#define TIM1_CH1N_F3_Pin GPIO_PIN_13
#define TIM1_CH1N_F3_GPIO_Port GPIOB
#define TIM1_CH2N_F2_Pin GPIO_PIN_14
#define TIM1_CH2N_F2_GPIO_Port GPIOB
#define TIM1_CH3N_F1_Pin GPIO_PIN_15
#define TIM1_CH3N_F1_GPIO_Port GPIOB
#define SPI1_NSS_Pin GPIO_PIN_15
#define SPI1_NSS_GPIO_Port GPIOA

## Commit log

2018-11-18 initial state, minimal loader and drivers pcb
    [RAMPS_1.4.2.3.kicad_pcb, RAMPS_1.4.2.3.sch]
2018-11-18 printf and cmdline works
2018-11-26 Using s3g write reg for LEDs
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2018-12-16 fix motor control pins
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2018-12-23 Setup TMC2130 by SPI
2018-12-23 motor muxes for full 6 channels
2018-12-23 motor muxes for full 6 channels (missed file)
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2018-12-30 Vitamins from nophead/Mendle90 and other places
    [ball-bearings.scad, bars.scad, belts.scad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]
2018-12-30 basic layout
    [top.scad]
2018-12-30 parametrize a bunch of things
    [top.scad]
2018-12-30 X assembly
    [top.scad]
2018-12-30 bigger wheels for Y axis
    [nylon-wheel.scad, top.scad]
2018-12-30 real size
    [top.scad]
2018-12-30 lower x bar
    [top.scad]
2018-12-30 y motor mount
    [top.scad]
2018-12-30 y idler mount
    [top.scad]
2018-12-30 printable parts
    [prints-y-corners.scad, top.scad, y-idler-corner.scad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]
2018-12-31 x-end top and bottom
    [prints-y-corners.stl, top.scad, x-end-plate.scad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]
2018-12-31 added by mistake
    [prints-y-corners.stl]
2018-12-31 print file for x-end
    [prints-x-end.scad, x-end-plate.scad]
2018-12-31 adjust based on real print
    [x-end-plate.scad]
2019-01-01 less debug
    [top.scad, x-end-plate.scad]
2019-01-01 more space for bar mount on top
    [x-end-plate.scad]
2019-01-12 v-slot color
    [v-slot.scad]
2019-01-12 x carriage base plate
    [top.scad, x-carriage-plate.scad]
2019-01-12 titan aero mount
    [x-carriage-plate.scad]
2019-01-12 print plate
    [prints-x-carriage.scad, x-carriage-plate.scad]
2019-01-12 print on other side
    [prints-x-carriage.scad]
2019-01-13 make it tight
    [nylon-wheel.scad, prints-x-carriage.scad, x-carriage-plate.scad]
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2019-01-20 Refactor OLED and SPI as well
2019-01-21 homing works on single axis
2019-01-27 make some internal regs shorter, so 3 endstops actually fit
2019-01-27 homing for all axes
2019-01-27 wait for end of homing
2019-01-27 profile code generation and abort on endstops work
2019-02-02 capture images from usb camera
2019-02-02 camera calibration and target pose detection
2019-02-03 track position on orange itself
2019-02-09 report back current X and V for each APG
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2019-02-17 switch a, j and jj to 16.8 fixed point
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2019-03-10 revert pin test
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2019-03-17 PoC for zencad based frame desicg
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2019-03-17 Connectors work at least to some extent :)
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2019-03-23 v-slot 20x20 with real profile
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2019-04-07 nema17 motors, self documenting units
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2019-04-07 linear rail - carriage MGN12H
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2019-04-14 GT2 pulley and idler
2019-04-14 pulley to belt connectors
2019-04-14 pulley and belts autoplacing
2019-04-14 curving belts around pulleys
2019-04-20 frame - stage 1 - XY: vslots + mgn
2019-04-20 frame - stage 2 - Y: motors and belts
2019-04-20 frame - stage 3 - X: motors and belts
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2019-05-19 All connectors for U carriages in place
2019-05-19 Y carriage - stage 1
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2019-08-31 all but 3d-printed parts
2019-09-01 rebuildable vitamins, no big files in git
    [coupler.FCStd, gp1s51.FCStd]
2019-09-07 original file and generated python
    [left_y_motor_plate.FCStd]
2019-09-07 switch to reexport mode
2019-09-07 switch to orig location
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2019-09-07 generated version
    [left_y_motor_plate.FCStd]
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2019-09-08 optoendstop and show printed parts in frame
2019-09-13 TCST2103 optointerruptor
    [tcst2103.FCStd]
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2019-09-14 move and rotate setup for 3dprint
    [left_y_motor_plate.FCStd]
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2019-10-13 current state of FreeCAD files
    `part -> *.py` workflow deprecated, most parts are just done in FreeCAD
    steppers_board_mount.FCStd - megafile with most of parts related to
    endstops/cable guides/etc.
    [left_y_carriage_plate.FCStd, left_y_idler_plate.FCStd, mgn12h.FCStd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]
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2019-10-13 thermocontrol board
    [thermocontrol-Board.gbr, thermocontrol-Bot.gbr, thermocontrol-BotMask.gbr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]
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2019-10-19 update to match current fpga and mechanics
    use both Y endstops to sync left and right Y motors
    update channels to axes mapping
2019-10-19 PSU mount
    [steppers_board_mount.FCStd]
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2019-10-27 Mutex for console out and PID targets support
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2019-11-02 Switch to handcrafted cmake, extract thermo task, build timestamp in banner
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2019-11-03 add uart rx queue and switch console to interrupt mode
2019-11-06 switch pid to doubles, work on temp instead on voltage
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2019-11-06 do not reset pid on small target changes
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2019-12-21 fix 6th endstop masks and black
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2019-12-30 Homing and abort buttons on UI actually work
2020-02-02 Use passed OLED, Z-homing with more space to tweak
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2020-03-15 fix emulator for untouched segments, formatting speedup, add extruder handling
2020-04-05 arm compatible variable types, better support for state keeping
2020-04-05 do not use analog current adjustments, set work and hold current
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2020-07-19 extruder planning works
    almost, there is some glitches on plato accel still
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2020-07-25 e acceleration caps, real extrusion speed is much more smoothed anyway
2020-07-26 switch linux to fpga baudrate to 500kbps, speed up other things
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2020-08-08 print timing stats and show traceback in case of error
2020-08-09 reallife max speeds for 1.75 and 3mm extruders
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2020-09-27 add little sleeps so another threads have a chance to run
2020-09-27 short segments filtering rework, fix espeed_by_de, dual extrusion adjustments
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2020-10-11 can skip disabled channels
    [pg_tb.v, profile_gen.v]
2020-10-31 correct generation of abort_done
    [profile_gen.v]
2020-10-31 step_gen, first approach, syntax is correct :)
    [pg_tb.v]
2020-11-01 ensure there is no errors
    [pg_tb.v]
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2020-11-21 handle invert dir at output pin level
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2020-11-22 wire in asg errors, kill one more SP, will optimize later (may be)
2020-12-06 fixed step bit to 40, reduced speed accumulators to 40 bit, better feedback for fifo_write
    [profile_gen.v]
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2021-06-12 fix priming of extruders
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2022-02-05 random additional files
    [camera_mount.FCStd, frame_assembly.FCStd, second_heater_holder.FCStd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]
2022-02-05 missing freecad files for printed parts
    [left_y_motor_plate.FCStd, left_z_rod_support.FCStd]
2022-02-05 Saved in new version of FreeCAD
    [left_y_motor_plate.FCStd, left_z_rod_support.FCStd]
2022-02-06 Rebuilt left_y_carriage_plate
    [left_y_carriage_plate.FCStd]
2022-02-06 resaved left_y_carriage_plate
    [left_y_carriage_plate.FCStd]
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2022-02-06 add printed parts from subfolder, optionally enable UI, so visibility is set
2022-02-06 opto endstop
    [optostop.FCStd]
2022-02-06 mounts for X endstops
    [left_x_opto_mount.FCStd]

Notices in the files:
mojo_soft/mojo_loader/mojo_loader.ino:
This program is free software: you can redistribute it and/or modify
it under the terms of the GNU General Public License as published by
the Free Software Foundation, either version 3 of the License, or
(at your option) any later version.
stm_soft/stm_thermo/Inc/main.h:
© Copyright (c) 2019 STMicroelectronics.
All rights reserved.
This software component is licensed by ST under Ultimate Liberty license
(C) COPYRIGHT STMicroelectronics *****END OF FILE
